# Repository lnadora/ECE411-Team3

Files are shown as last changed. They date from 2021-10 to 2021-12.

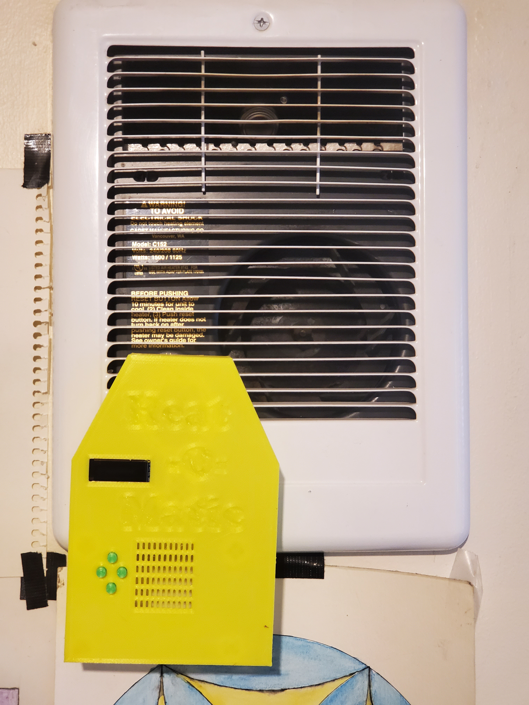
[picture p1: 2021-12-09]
20211205_145641.jpg

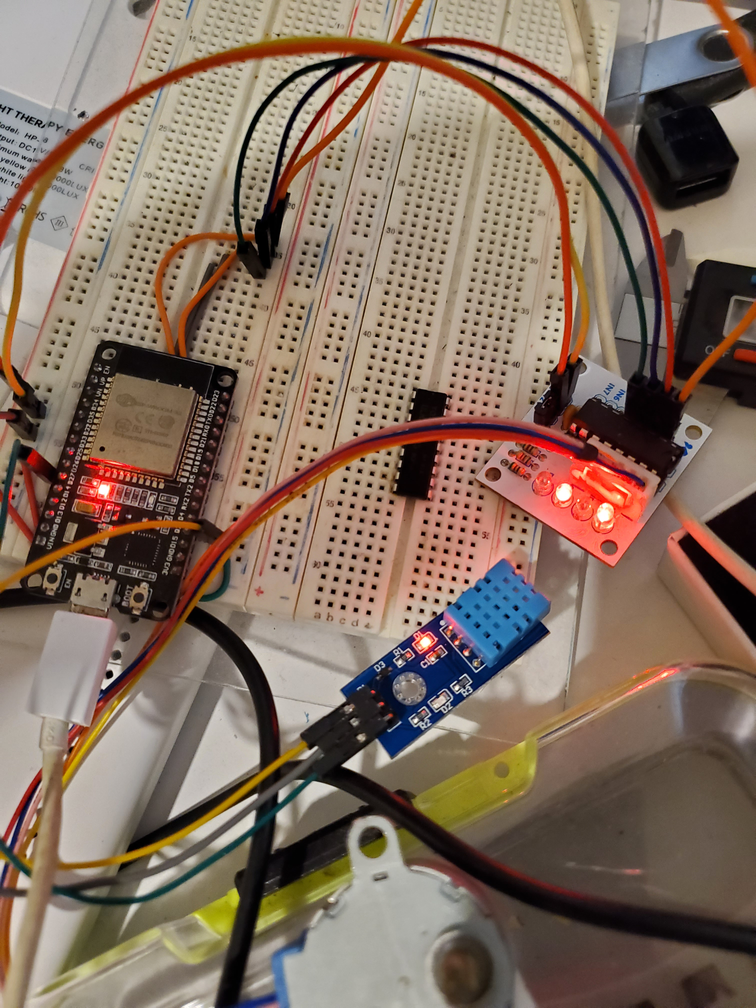
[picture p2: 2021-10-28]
Assignment Documentation/Week5 Assignment/breadboard.jpg

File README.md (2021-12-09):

# ECE411-Team3
Practicum Project for ECE 411

The project will attempt to connect ESP32 to the internet. After user use their device(phone,ipad,pc etc) connect with the wifi, Esp32 wifi module will send the Ip to the user.User can according to the IP go into the website and achieve the website interact.
To erase the credentials stored on the ESP32:     
    1.) uncomment the line:     
  ```//ESPAsync_wifiManager.resetSettings();   //reset saved settings:```     
    2.) upload and reset the ESP32, your credentials will be deleted.     
    3.) recomment the line     
    4.) reupload and reset the ESP32     

Once connected the device will present an IP address where the website is hosted on your local network.

Current program functionality:

    - Connects to the internet
    - Retrives temp from the sensor
    -- Samples every x seconds set by DHT_UPDATE_DELAY (currently every 1s)
    --- Should be changed to just using millis()
    - Prints temp,current and set temperature,and Ip  on the OLED
    -- Uses U9g2 library.
    --- lots of examples in the examples folder.  
    --- left some example code in the program commented out
    - Buttons move the stepper motor
    -- BUTTON_A turon on the system
    -- BUTTON_B tuen off the system
    -- BUTTON_C Increase the setting tem
    -- BUTTON_D decrease the setting tem
    -- Buttons labeled as BUTTON_A, BUTTON_B, BUTTON_C, BUTTON_D
    --- Button pins are 26,25,33,14 respectivly
    - Website can control stepper motor
    - Website can achieve the stable temperature system
    -- Through some exprimenting it was found how the data is transmitted
    --- This is documented in the .js file and the .cpp file.
    
Needs to be done

    -Menu
    -- Setup
    --- set time
    --- set leave time
    --- set arrive time
    - Change the timing function to millis()

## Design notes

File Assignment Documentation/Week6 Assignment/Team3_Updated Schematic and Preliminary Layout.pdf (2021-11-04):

Week 6 Schematic and Layout Team 3
11/4/2021
Notes:
- We still need to add a barrel jack and a AMS1117 3.3v voltage regulator to provide clean power to the board from a wall adapter. We got to this part late and would like to test it on the breadboard before we update the schematic as it works fine as it is now.
- The DHT11 will not be soldered to the board like it shows in the 3d view
- Annotating is still confusing… luke will make some edits to the screen printing

The Schematic for our design:

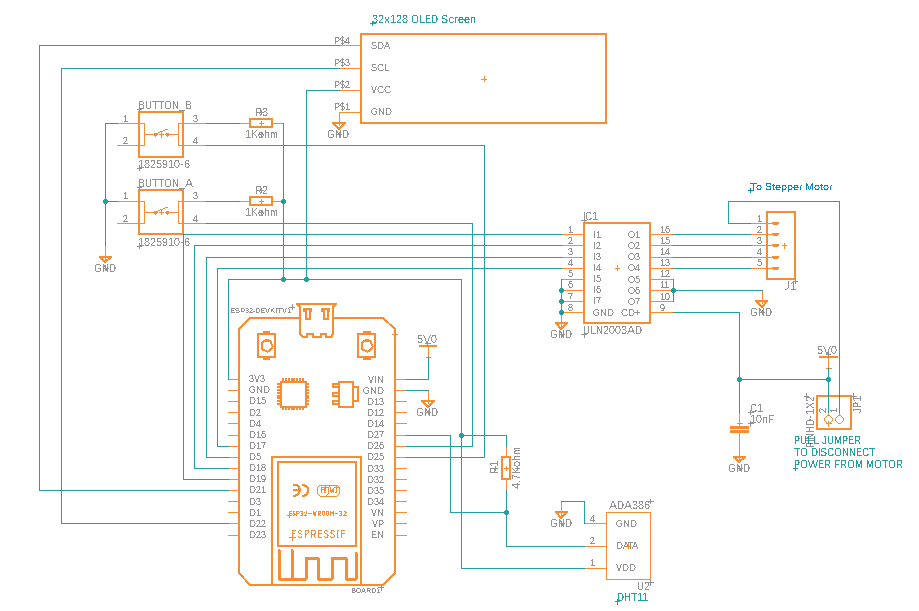
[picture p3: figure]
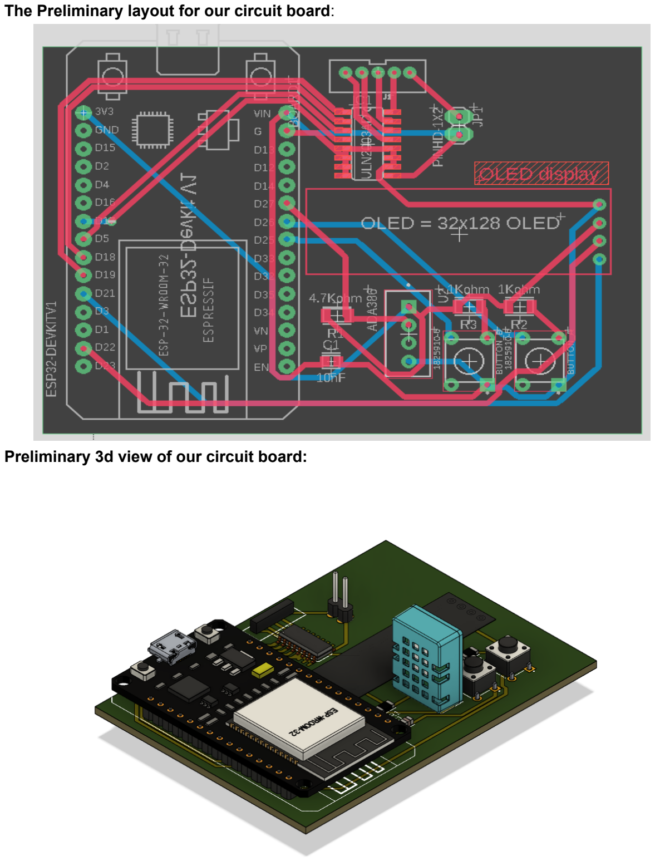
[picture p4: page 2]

The Preliminary layout for our circuit board:

Preliminary 3d view of our circuit board:

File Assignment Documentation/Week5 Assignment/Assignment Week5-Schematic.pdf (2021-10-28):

Practicum week 5: Schematic
Link to schematic: https://github.com/lnadora/ECE411-Team3/tree/main/CircuitBoard (schematic is made in Fusion 360 but exported as an Eagle filetype)

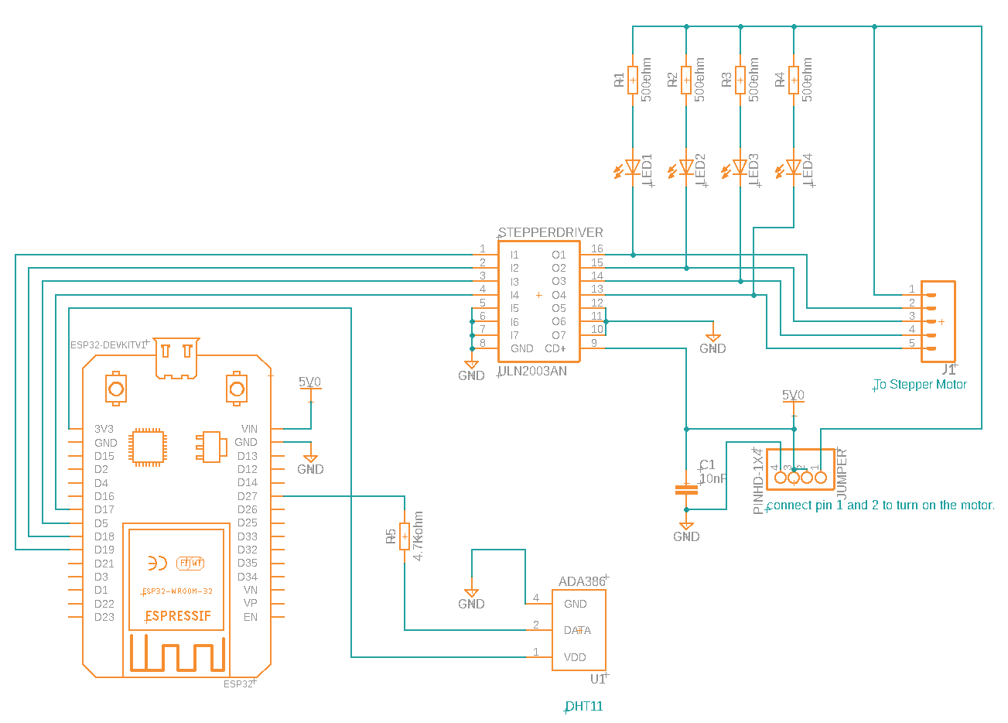
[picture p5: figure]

Todo:
1. Investigate separating the power of the motor from the power of the ESP32.
2. LED’s turn on when the motor is running… Pointless? Idk… They show the speed of the motor… but they flash really fast and it will be inside the case.
3. Use a power supply instead of USB to ESP to power the device
4. Change the DHT data line resistor R5 to a pull-up resistor connected to the 3.3v instead of inline to the data pin
5. Add buttons to manually turn the heater on or off
6. Look into BMS systems and see if it would be practical to implement a battery to our system

How it works
1. The ESP32 passes 5v through the USB port to the VIN pin.
a. We currently power the stepper motor with that 5V pin
2. Originally we powered the DHT11 with the +5V VIN pin. But since our ESP32 has 3.3v datalines the 5V was too much for them and produced many errors reading the temp.

3. The 4x1 pin jumper is a male header… But we really only need 2 pins to use a jumper that disables the stepper motor when removed.

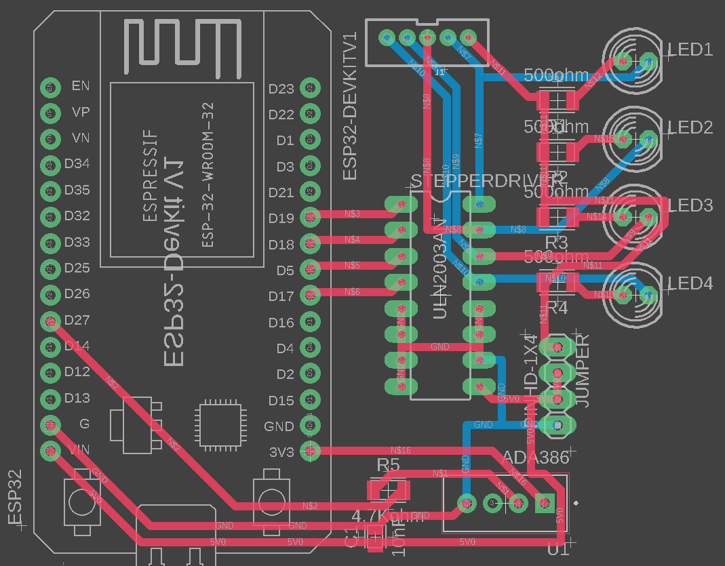
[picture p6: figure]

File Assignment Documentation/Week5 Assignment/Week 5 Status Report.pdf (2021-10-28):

Week 5 Status Report
Team 3
10/27/2021
Project Summary:
Our project is coming along nicely. So far we have our schematic for the PCB designed and all of our components are working with example code.

Completed Tasks for the week:
1. VS code and PlatformIO installed.
2. Build the circuit on the breadboard.
3. Use example code to make sure the parts we have work
4. Some basic testing based on the current code.
5. Using Fusion 360, we made the schematic of the circuit
6. Started a GANTT chart to keep everyone on track.

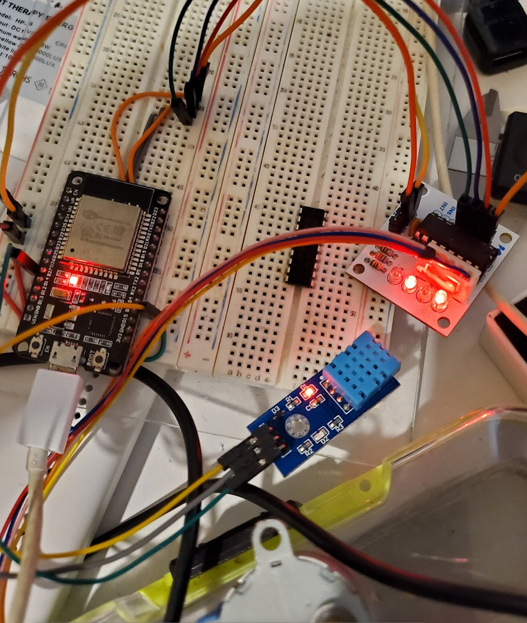
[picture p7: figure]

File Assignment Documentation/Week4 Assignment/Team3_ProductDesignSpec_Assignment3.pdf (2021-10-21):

## Product Design Specification

Team 3: Kai Han, Luke Hoskam, Luis Nadora, Zheng Zhang Professor Greenberg
ECE411
10/20/2021

### Executive Summary / Concept of Operations

Many apartment dwellers would like to have smart devices in their house but cannot because of the relative permeance of some devices. A heater in an apartment, for instance, may only present a user with a dial style thermostat knob to set an abstract temperature. This would leave no option to attach a smart thermostat. This would force an energy conscious renter to adjust the knob manually every time he left his apartment and when he returned.
Our device aims to fix that by attaching non-destructively to the thermostat knob and allow the user to program temperature settings though their local intranet.So people who are limited by the relative permeance of some devices but also would like to make the heater smarter will use it. The device will host a small webpage to allow the user to program either a constant temperature or set on-off times, for instance, automatically turn off when the user is at work. Basically, this device turns your standard knob controlled heater into a programmable thermostat without having to remove or damage parts of the building or equipment owned by the landlord.

### Brief Market Analysis

The intended customers are apartment dwellers who would like a smart heater but already had a dumb heater and renters who have a limited budget but want to maintain a constant temperature better the knob is capable. The device will non-destructively attach to the already installed heater knob and manipulate its inputs.
For now, our competitors are mainly manufacturers with complete replacement heating systems. If landlords replace the heater system with a smart heater, it will affect our sales of our project. The best aspect of our project is that we do not need to replace the original heater (which is not the property of the tenant), which can reduce waste. Replacing the heater will not only damage the walls or facilities in the original apartment, but also create a lot more waste. Thus, we will create a device that allows people to non-destructively convert an existing heater with a thermostat knob to a smart heater. The networked heater will also be controlled ‘smartly’ on the intranet. It not only saves electricity but also makes it easier and more fun to control the heater. Another type of competition is portable heaters, which are controlled/programmed by a smartphone app.
The price range for the permanently installed and portable smart devices is anywhere from $60-$250 and we are positive that we can build and sell our device within that price range.

### Requirements

Must requirements:
- Be lightweight
- Non-destructively attach to a heater knob
- Interface with the device through website
- Allow users to program on-off times through the website.
- Have a case
- Have a manufactured PCB
Should requirements:
- Powered by a battery
- Have an attractively designed case.
- Interface with buttons to control the motor.
May requirements:
- Realize the internet to control the temperature.
- Connect wirelessly to auxiliary thermostats to maintain an average set temperature.
- Have a display

### System Architecture

Level 1 Block Diagram for the Smart Heater

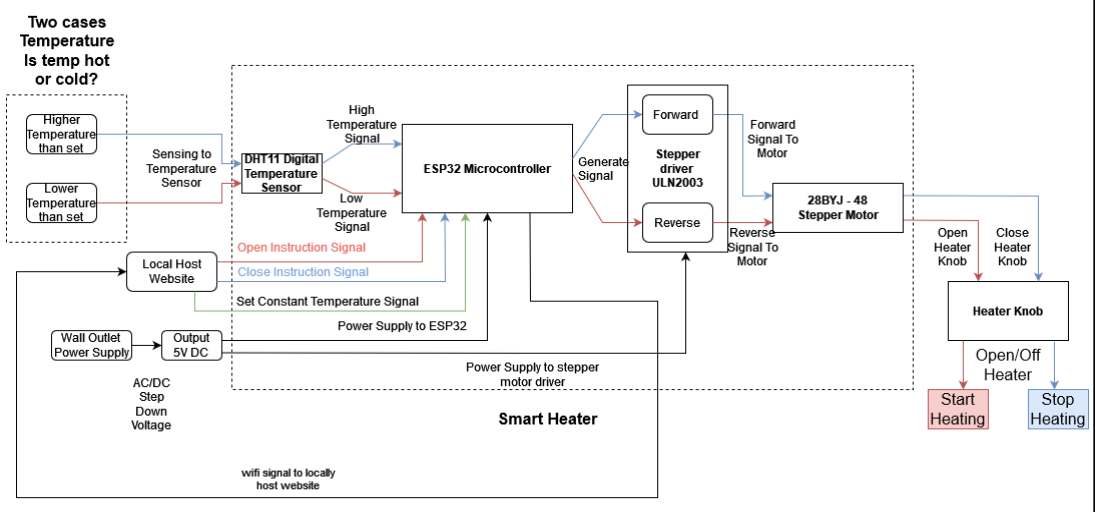
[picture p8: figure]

### Design Specification

- Processor: ESP Wroom 32 Devkit V1. 4
- The ESP Wroom 32 is a low-cost development board with a Dual-core CPU Xtensa LX6 clocked at 250MHz. It has: 25 digital I/O pins, 6 Analog inputs, and 2 digital-to-analog output pins, and 4MB of storage.
- Our project will use the ESP32 to process the signal from the DHT11 and, when appropriate, signal the stepper driver to manipulate the heater knob.

- Sensor: Temperature Sensor (DHT11) x 1.
- The DHT11 is a basic, ultra low-cost digital temperature and humidity sensor. It uses a capacitive humidity sensor and a thermistor to measure the surrounding air and outputs a digital signal on the data pin (no analog input pins needed).
- The project uses DHT11 sensors to detect the room temperature and then compare that temperature to the set temperature on the ESP32.
- Actuator: Stepper motor(28BYJ - 48) and Driver (ULN2003)x 1.
- Powered with 5v from the AC-DC wall adapter, the ULN2003 is a 16-pin IC. It has seven Darlington Pairs inside, where each can drive loads up to 50V and 500mA.
- 28BYJ-48 is a small, lightweight, unipolar, 5V stepper motor that inputs alternating pulse signals and rotates by converting these input signals into mechanical rotation by selectively turning on and off specific electromagnets.
- Our project will have 5v DC to the ULN2003 common pin. Then, when the ESP32 sends an HIGH signal to a particular pin on the ULN 2003 will output a clean 5v to the stepper motor. The stepper motor will connect to the heater knob through gears to turn the heater on and off.
- Power: E178074 AC-DC wall adapter.
- Input: 100-240AC,
- Output: 5v 1A wall adapter.
- Mechanical Design: Designed in Fusion 360 and printed using a 3D Printer.
- The software we will use to design the gears and the case will be Fusion 360. We will print the parts on one of three printers owned by group members.
- The case will include an opening for the DHT11 to extend outside the case. The circuit board, motor, gears and microcontroller will be inside the case.
- Development environment: Visual Studio Code, PlatformIO and GIT.
- We will use Visual Studio Code with the PlatformIO extension to program the ESP32.
- The group will stay connected and up to date with the project using GIT through github.com (https://github.com/lnadora/ECE411-Team3)

### Primitive CAD drawing

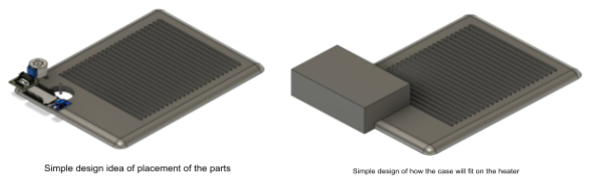
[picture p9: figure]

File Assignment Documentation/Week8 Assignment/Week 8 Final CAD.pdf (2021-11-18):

W

e

e

k

8

Fin

al C

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
tic:

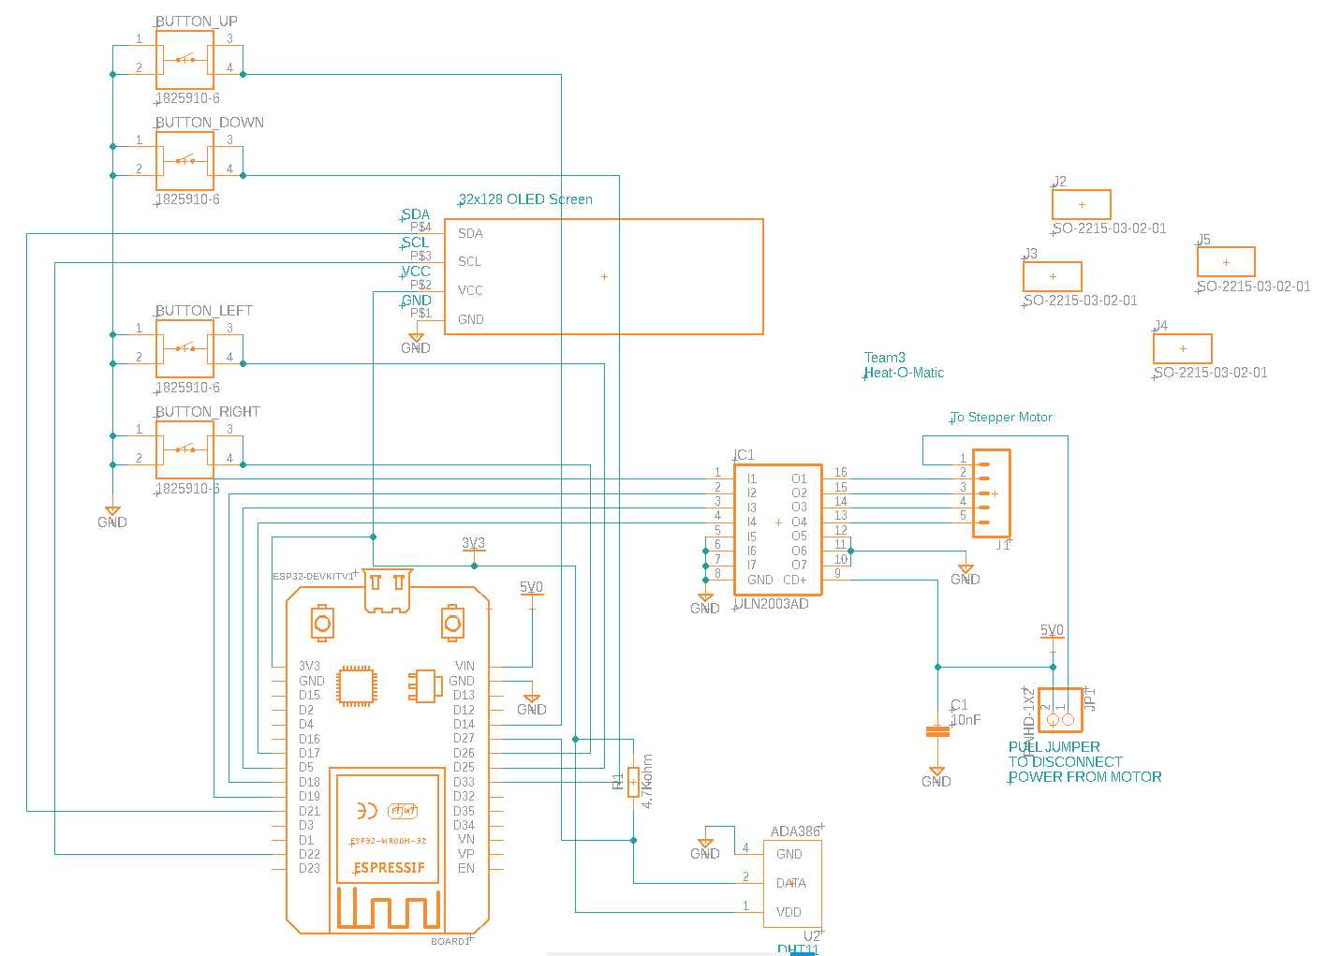
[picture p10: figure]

Board Layout:

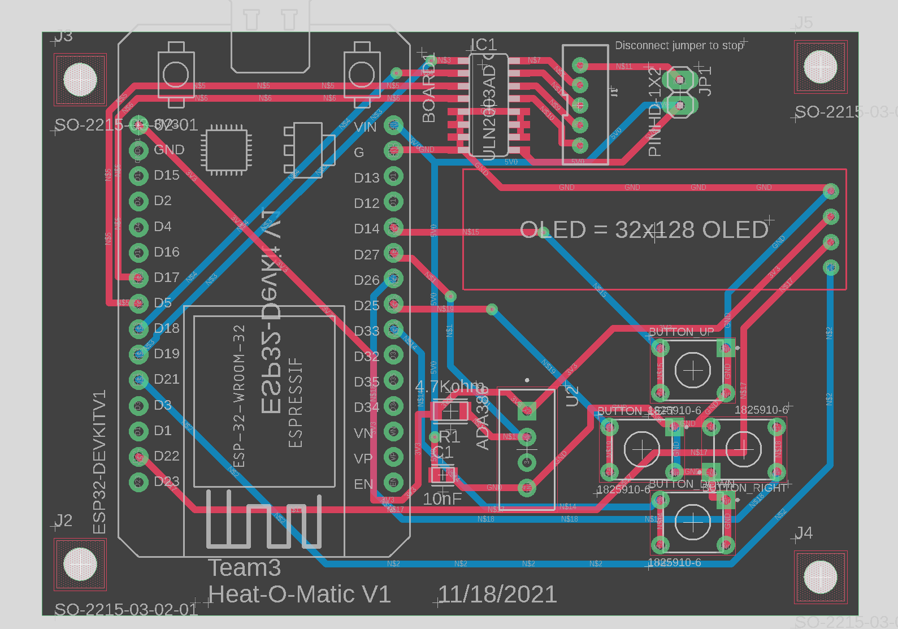
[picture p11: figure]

3d Model of board:

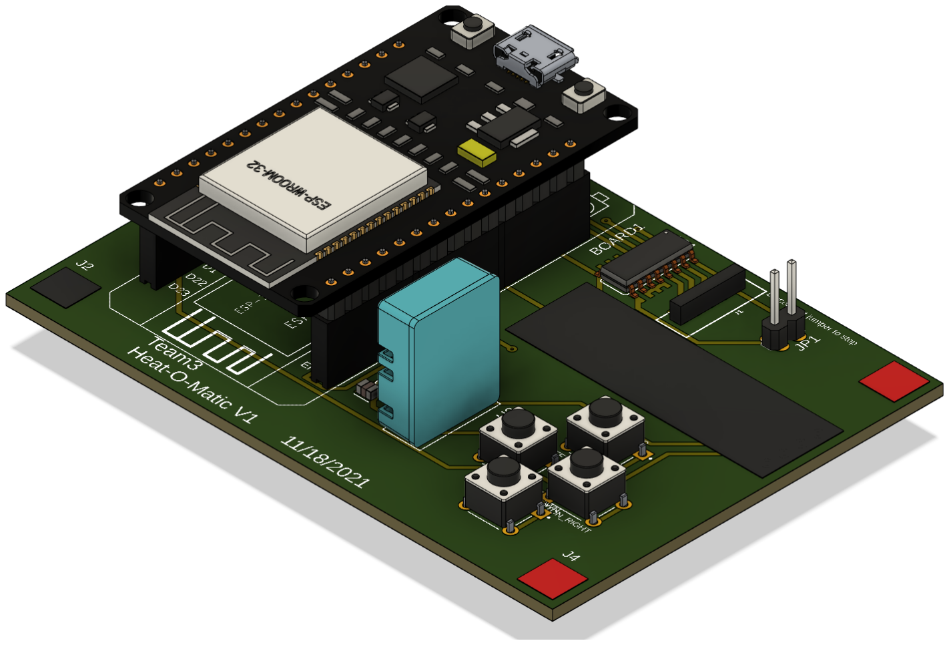
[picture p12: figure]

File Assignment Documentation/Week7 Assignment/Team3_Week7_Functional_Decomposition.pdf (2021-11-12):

# ECE 411 Team 3 Functional Decomposition for the Smart Heater System

Team Members: Kai Han, Luke Hoskam, Luis Nadora, Zheng Zhang

Level 0 Block Diagram

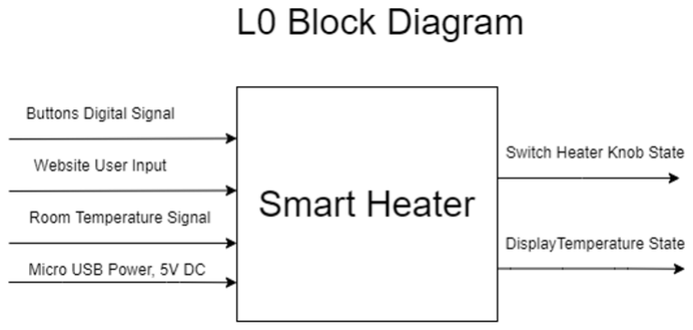
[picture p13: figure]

Module | Smart Heater
Inputs | Power: 5V dc. Buttons: Sends a digital signal to apply the settings desired by the user Room Temperature Signal: Sends a digital signal of ambient temperature and humidity Website User Input: Local website send user input data and getting feedback from microcontroller to declare when to turn the knob
Outputs | DisplayTemperature State: Smart heater sends data using the I2C protocol to the OLED screen to display temperature state Switch Heater Knob State: The stepper motor receives a digital signal turning the knob position.
Functionality | The Smart Heater turns the knob on a heater unit a certain amount of steps to turn the heater on or off. The start and end time for the system is determined by the user through the WebSocket website, as well as the desired room temp at that time. Buttons are used to set the start and end times of the system without going through the website. The ambient temperature and humidity of the room is also displayed on the OLED display screen for the user to read.

Level 1 Block Diagram

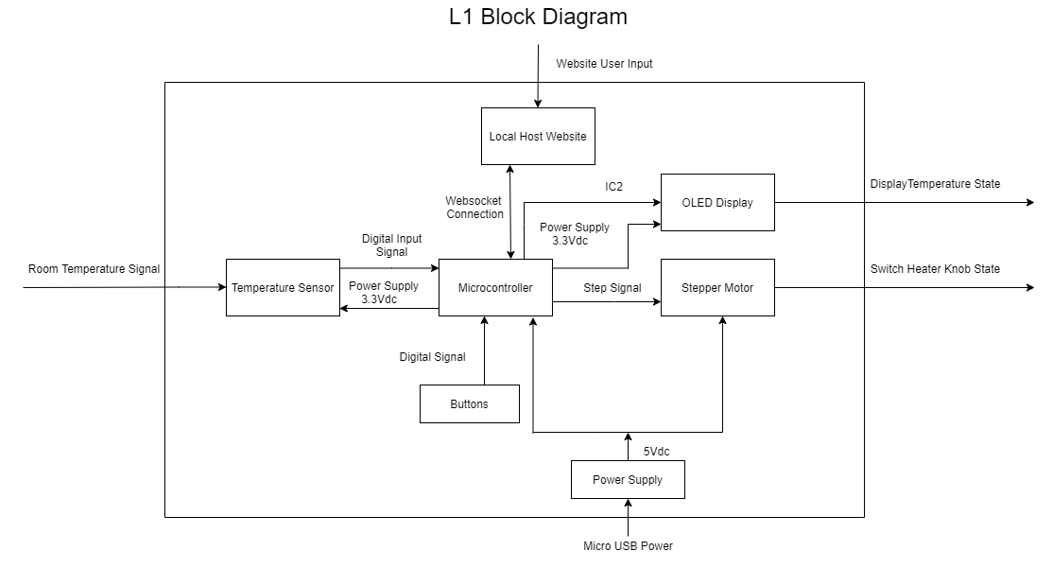
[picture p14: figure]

Temperature Sensor: Level 1

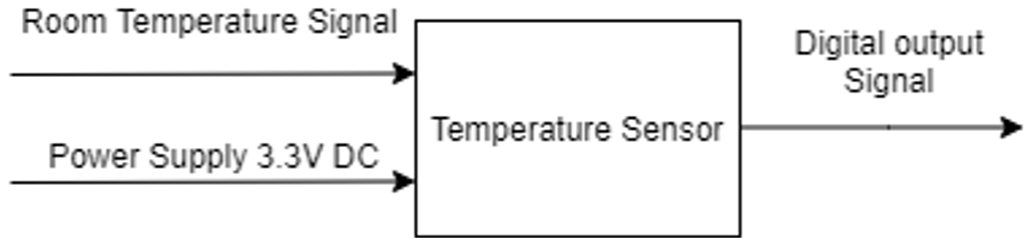
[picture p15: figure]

Module | Temperature Sensor
Inputs | Power: 3.3V dc from microcontroller Room Temperature Signal：Sends a digital signal of ambient temperature and humidity
Outputs | Digital output signal: Get the current temperature and humidity data from the sensor, and send a digital signal to the microcontroller.
Functionality | Sensing the surrounding temperature and sending a digital signal to the microcontroller

Microcontroller: Level 1

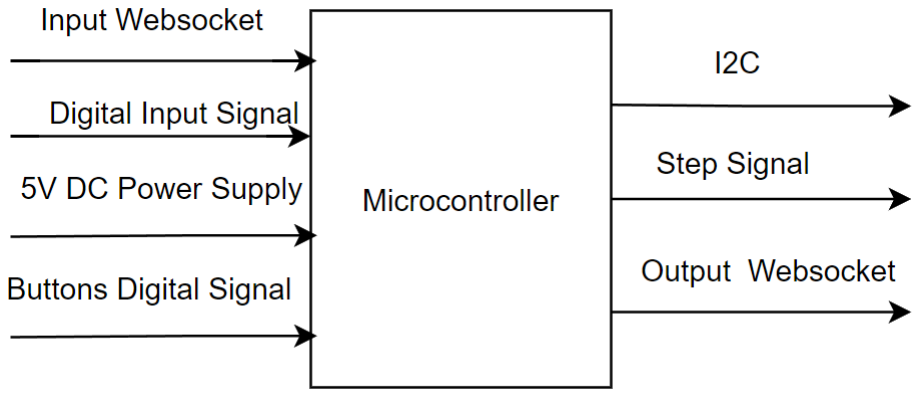
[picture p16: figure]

Module | Microcontroller
Inputs | Input Websocket ：Local website sends user input data to declare when to turn the knob Digital input signal：Ambient temperature data from the temperature sensor, to be used to compare the ambient temperature with the set temperature to determine whether it is consistent Power supply：5V DC Buttons：Manually control smart heater switch, timer
Outputs | I2C：Sends data for the OLED screen to display temperature state Step signal: Signal sent to the stepper motor to change the knob position Output websocket：Microcontroller establishes WebSocket Connection to setup the local website
Functionality | The microprocessor can complete operations such as fetching instructions, executing instructions, and exchanging information with external memory and logic components

Local Host Website: Level 1

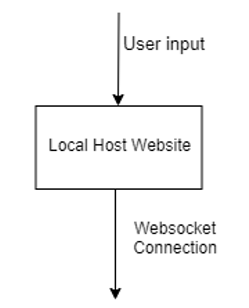
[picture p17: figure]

Module | Local host website
Inputs | User Input： The user gives instructions to the webpage by visiting the webpage, choosing the temperature and starting time the user would like.
Outputs | Websocket connection: Local website sends user input data through the Websocket connection to the microcontroller, thus communicating the desired start and end times for the heater to be turned on.
Functionality | Our project hopes to showcase the “smartification” of the heater through web design. The user gives instructions to the webpage to get the function they desire.

Stepper Motor: Level 1

Module | Stepper motor
Inputs | Power: 5Vdc Step signal: Send a continuous and stable signal to the motor to make the motor rotate
Outputs | Switch heater knob state:The stepper motor receives the step signal, turning the knob position.
Functionality | The motor has a gear system attached to it so that it has enough torque to rotate the heater system control knob.

OLED Display: Level 1

Module | OLED display
Inputs | Power: 3.3V DC Voltage I2C: The data from the microcontroller telling the OLED screen what to display
Outputs | Display temperature state: OLED Screen displays the current temperature and humidity information of the room.
Functionality | The OLED Screen displays the current temperature and humidity of the room according to the I2C protocol sent by the microcontroller.

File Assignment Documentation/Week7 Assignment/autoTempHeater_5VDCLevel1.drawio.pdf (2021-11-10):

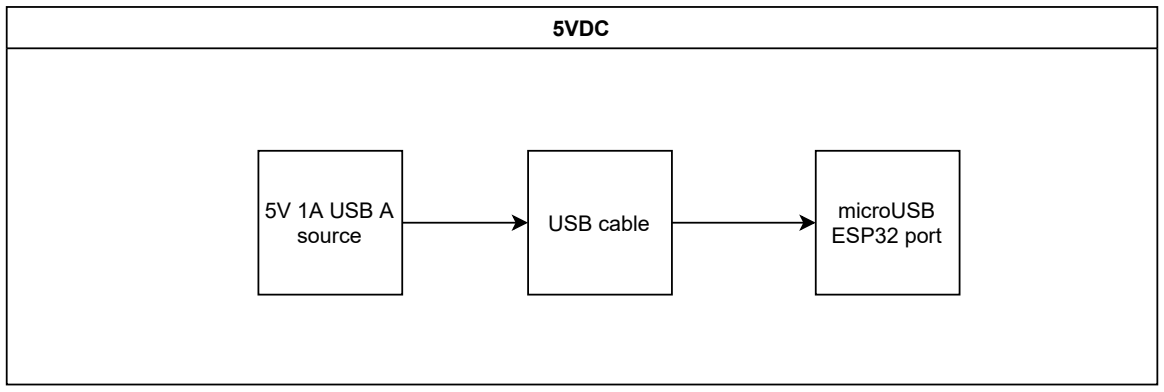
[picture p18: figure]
5VDC; 5V 1A USB A source; USB cable; microUSB; ESP32 port

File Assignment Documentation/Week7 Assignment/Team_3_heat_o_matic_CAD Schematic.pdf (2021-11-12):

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
tic:

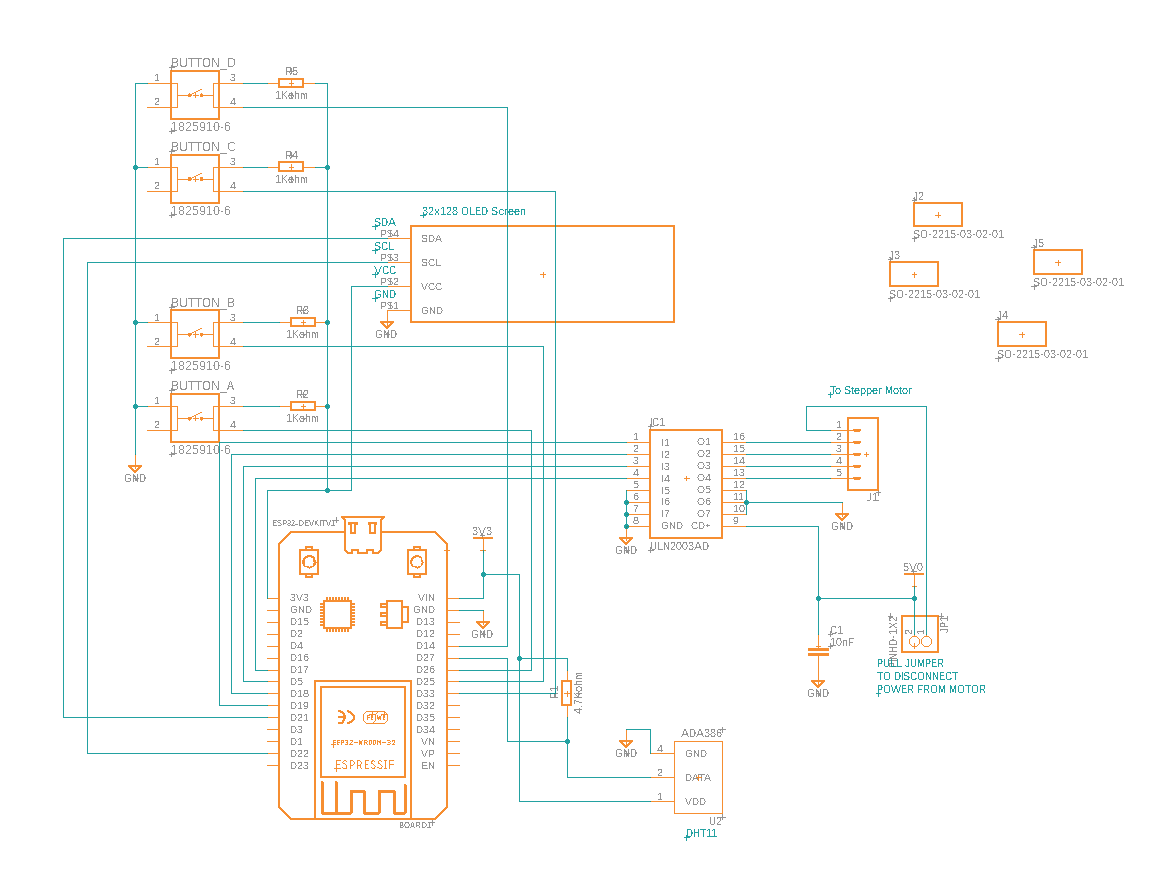
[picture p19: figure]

Layout:

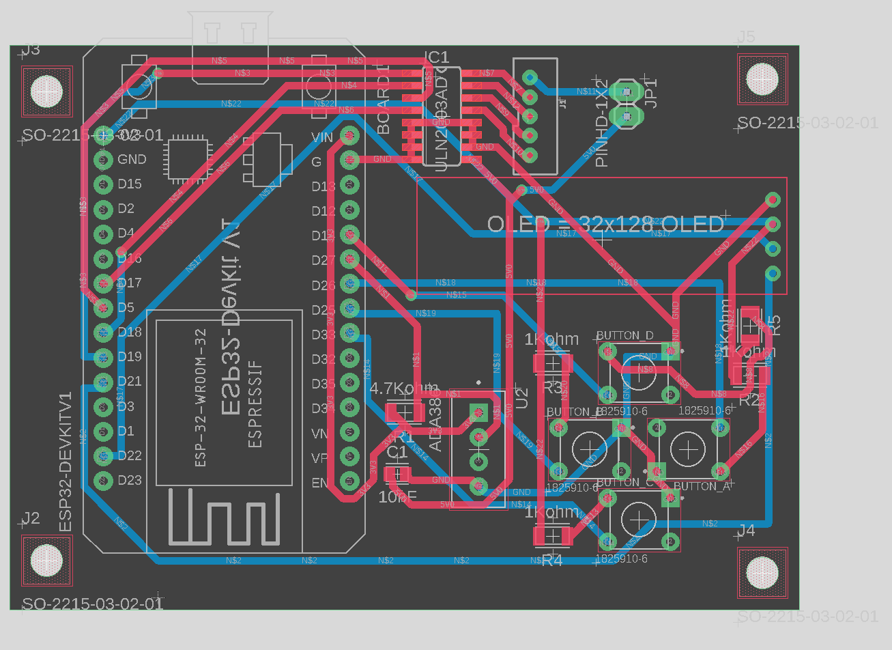
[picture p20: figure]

3d Model:

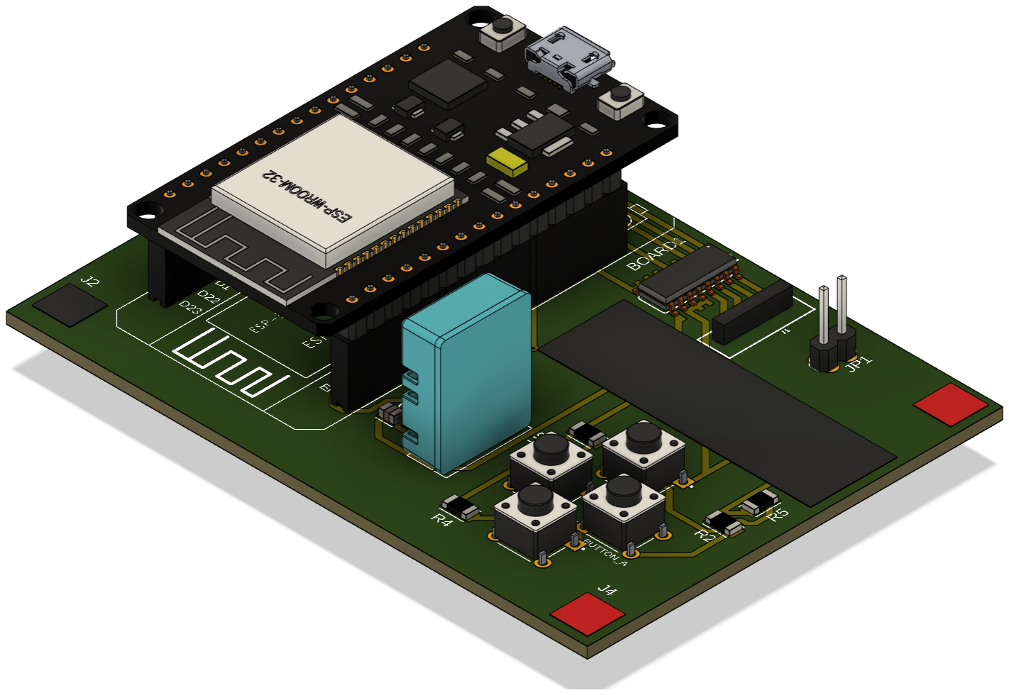
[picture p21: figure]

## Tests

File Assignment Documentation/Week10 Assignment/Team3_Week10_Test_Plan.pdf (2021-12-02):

## Week 10 Test Plan Team 3 “Heat-o-Matic”

12/03/2021

## Team Members: Zheng Zhang, Luis Nadora, Luke Hoskam, Kai Han

Test Author:Zheng Zhang

Test Case Name: | System test | Test ID #:
Description: | Test system by using different methods to change the temperature of the environment, so as to observe after the smart heater has passed the webpage default temperature of 24°C. The heater can be switched on and off by changing the indoor temperature | Type: | □ white box ☑ black box □ _____________

Tester Information
| Name of Tester: | Zhengzhang, Kai Han | Date: | 11/27/2021
| HW/SW Version: | 1.0 | Time: | 2:00 pm
| Setup: | Use a hair dryer to raise the temperature for the DHT11 temperature sensor, and place it outdoors to reduce the temperature to simulate the indoor temperature
TEST | Action | Expected Output： stepper motor state | PASS | FAIL | N/A | Comments
1 | Open the window and place the board outside the window to lower the sensor temperature to 20 °C | The stepper motor rotates 180° and the heater turns on | | | | Setting temperature less than the indoor temperature，system start to work，stepper motor rotates 180° and the heater turns on
2 | Use a hair dryer to raise the temperature sensed to 26°C | The stepper motor rotates 180° and the heater turns off | | | | Setting the temperature over the indoor temperature，system does not work，the steeper turns back to the original position.
3 | Use a hair dryer to raise the temperature sensed to 28°C | The stepper motor not move and the heater turns off | | | | Increasing the temperature after the system has already turned on the heater，the system keep to stay off.
4 | Open the window and place the board outside the window to lower the sensor temperature to 20 ° | The stepper motor rotates 180° and the heater turns on | | | | Setting the temperature smaller than the indoor temperature，the system turns on again, stepper motor rotates 180° and the heater turns on
| Overall test result: | | | | | The project can perfectly work with the temperature change.

Detailed Description：Our project depends on the user setting the temperature to tell the system to turn the heater on or off. Users will set the specific temperature on the website, the DHT11 sensor will detect the temperature and send a digital signal to the esp32 microcontroller to move the heater knob in the appropriate position via the stepper motor. Therefore, proper communication between the input temperature and output stepper motor control is very important. We will test the system by simulating indoor temperature and using different methods to change the temperature of the environment, so as to observe the result after the smart heater has passed the webpage default temperature of 24°C. The heater should be switched on or off depending on the indoor temperature.

Test Author: Zheng Zhang

Test Case Name: | Component tests | Test ID #:
Description: | Test to confirm the basic function of the heat-o-matic project. | Type: | ☑white box □ black box □ ________

Tester Information
| Name of Tester: | Zheng Zhang, Kai Han | Date: | 11/30/2021
| HW/SW Version: | 1.0 | Time: | 4:00pm
| Setup: | Build the circuit on the breadboard and test the basic function of each component.
STEP | Test part: | Expected Result | PASS | FAIL | N/A | Comments
1 | DHT11 temperature sensor | DHT 11 can detect the surrounding temperature | | | | The temperature sensor sometimes displays packet loss behavior, and occasionally displays nan°, but because the temperature sensor refreshes in real time and the frequency is twice per second, it does not affect the use of the function
2 | Stepper motor | Stepper motor can accept the digital signal to Rotate 180° | | | | The motor can successfully receive the signal to complete the work
3 | Website display | Website can accept the ESP 32 offer IP , also can create it on the local host and normally display current temperature, user setting temperature, and system status | | | | When multiple people connect to the same wifi hotspot, it may cause the website to display normally， should fix this bug.
4 | OLED display | OLED can display the current temperature，user setting temperature and website IP | | | | The OLED connection is correct and properly displays the information for the user
5 | Websocket Connection | Users can use the website to set the expected temperature to make the heater turn on or off. | | | | Websocket connection works properly between esp32 and the website.
| Overall test result: | | | | | The basic functions can be implemented very well. Although the DHT11 occasionally loses packets, it does not affect the use. The occasional behavior that cannot be displayed on the multi-person connection web page needs to be repaired.

Detialed Description：To make sure the project works well, we need to do the white box test to make sure every part of the project works well. So we will build each different part on a breadboard, to test if the function of every component works properly. We must test if the DHT11 temperature sensor can detect the surrounding temperature correctly, if the stepper motor can accept the digital signal to Rotate 180° to turn on or off the system, if the website can be created properly on the local host. We must also test if the OLED can display the current temperature, the desired temperature, and the website IP for the Websocket Connection so that the user can set the desired temperature from the website.
If each part individually functions properly then it illustrates that the function of the system as a whole functions properly as well.

Test Author:Luis Nadora

Test Case Name: | Button Test | Test ID #:
Description: | Press each button to ensure that it is being detected properly by the ESP32 Microcontroller. | Type: | □ white box ☑ black box □ _____________

Tester Information
| Name of Tester: | | Date:
| HW/SW Version: | 1.0 | Time:
| Setup: | Observe the confirmation of each button press by looking at the output script via microcontroller program on the monitor.
TEST | Action | Expected Output： | PASS | FAIL | N/A | Comments
1 | Press Button A | Output Script on the monitor saying “Button A Was Pressed”
2 | Press Button B | Output Script on the monitor saying “Button B Was Pressed”
3 | Press Button C | Output Script on the monitor saying “Button C Was Pressed”
4 | Press Button D | Output Script on the monitor saying “Button D Was Pressed”
| Overall test result:

Detailed Description: The purpose of this test is to simply ensure that each of the buttons are correctly connected to the system and communicate properly with the rest of the system through the microcontroller. A simple program will be needed in order to conduct this test. If the result of any of the button tests results in a failure, there may be something incorrect with the assembly of the system. Check to ensure that the buttons are correctly connected to the appropriate pins of the microcontroller, and check the program to make sure that there are no errors resulting from the test code.

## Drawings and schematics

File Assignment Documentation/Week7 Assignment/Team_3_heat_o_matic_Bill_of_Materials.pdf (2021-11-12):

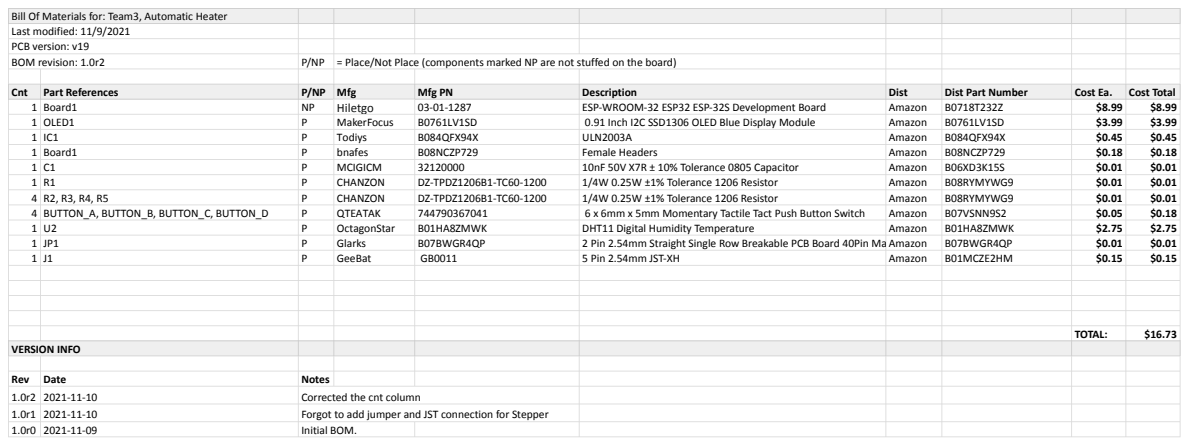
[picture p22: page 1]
BOM revision: 1.0r2; P/NP = Place/Not Place (components marked NP are not stuffed on the board); Cnt; Part References; P/NP Mfg; Mfg PN; Description; Dist; Dist Part Number; Cost Ea.; Cost Total; 1 Board1; Hiletgo; ESP-WROOM-32 ESP32 ESP-32S Development Board; Amazon; 1 OLED1; MakerFocus; 0.91 Inch I2C SSD1306 OLED Blue Display Module; Todiys; B084QFX94X; ULN2003A; bnafes; B08NCZP729; Female Headers; MCIGICM; 10nF 50V X7R ± 10% Tolerance 0805 Capacitor; CHANZON; DZ-TPDZ1206B1-TC60-1200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

Bill Of Materials for: Team3, Automatic Heater
Last modified: 11/9/2021
PCB version: v19

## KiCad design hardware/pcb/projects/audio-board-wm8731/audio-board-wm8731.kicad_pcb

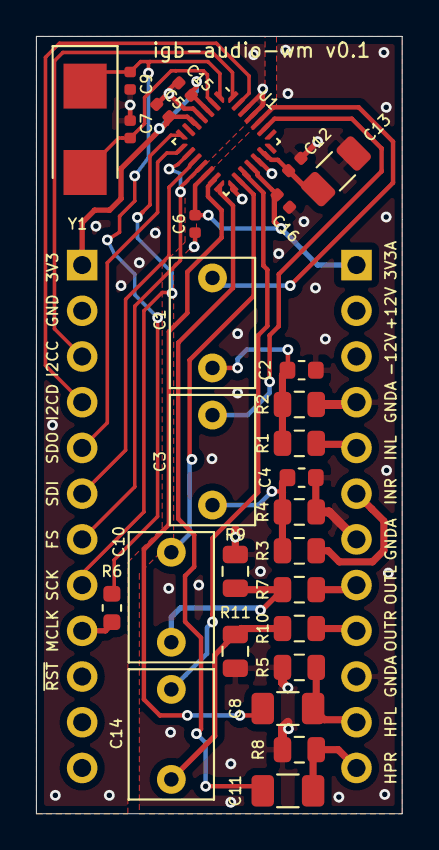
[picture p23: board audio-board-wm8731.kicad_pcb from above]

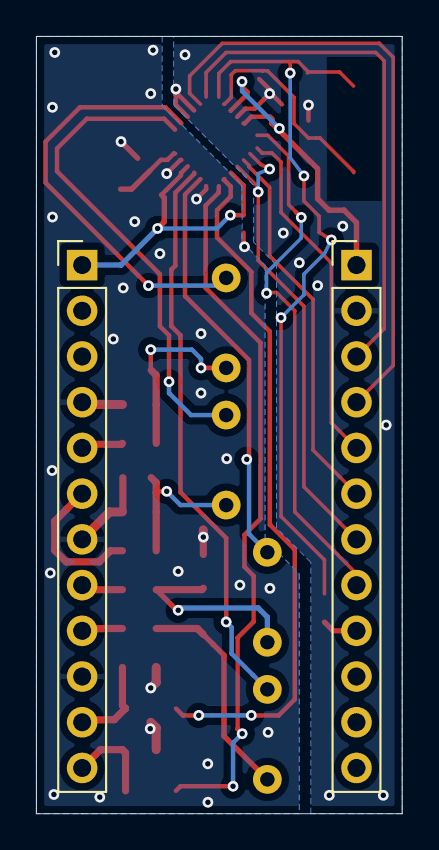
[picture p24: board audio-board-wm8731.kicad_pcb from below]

Board: 2 copper layers, 20.3 x 43.2 mm, 31 parts (2 on the bottom side), 30 nets.

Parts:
C1, C3, C10, C14: 1u; C_Rect_L7.0mm_W4.5mm_P5.00mm
C2, C4: 220p; C_0603_1608Metric
C5, C6, C12, C15, C16: 100n; C_0402_1005Metric
C7, C9: 18p; C_0402_1005Metric
C8, C11: 100u; C_1206_3216Metric
C13: 10u; C_1206_3216Metric
J1, J2: Conn_01x12; PinHeader_1x12_P2.54mm_Vertical
R1, R2, R3, R4: 10k; R_0805_2012Metric
R5, R8, R9, R11: 100k; R_0805_2012Metric
R6: 0; R_0603_1608Metric
R7, R10: 100; R_0805_2012Metric
U1: wm8731_qfn; QFN-28_4x4mm_P0.5mm
Y1: 12.288MHz; Crystal_SMD_Abracon_ABM3-2pin_5.0x3.2mm_hand

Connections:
+3.3VA: C6.2, C16.2, J1.1, U1.12, U1.18
+3V3: C5.2, C15.2, J2.1, U1.3, U1.5
/ADC_L: C1.2, U1.24
/ADC_R: C3.2, U1.23
/DAC_L: C10.2, U1.16
/DAC_R: C14.2, U1.17
/HP_OUT_L: C8.2, J1.11, R5.2
/HP_OUT_R: C11.2, J1.12, R8.2
/I2C_SCL: J2.3, U1.28
/I2C_SDA: J2.4, U1.27
/I2S_FS: J2.7, U1.9, U1.11
/I2S_MCLK: J2.9, R6.1
/I2S_SCK: J2.8, U1.7
/I2S_SDI: J2.6, U1.10
/I2S_SDO: J2.5, U1.8
/LINE_IN_L: J1.5, R1.2
/LINE_IN_R: J1.6, R3.2
/LINE_OUT_L: J1.8, R7.2
/LINE_OUT_R: J1.9, R10.2
GND: C5.1, C7.2, C9.2, C15.1, J2.2, U1.4, U1.25, U1.26
GNDA: C2.1, C4.1, C6.1, C12.2, C13.2, C16.1, J1.4, J1.7, J1.10, R2.2, R4.2, R5.1, R8.1, R9.1, R11.1, U1.15, U1.19
unnamed: C1.1, C2.2, R1.1, R2.1
unnamed: C3.1, C4.2, R3.1, R4.1
unnamed: C7.1, U1.2, Y1.2
unnamed: C8.1, U1.13
unnamed: C9.1, R6.2, U1.1, Y1.1
unnamed: C10.1, R7.1, R9.2
unnamed: C11.1, U1.14
unnamed: C12.1, C13.1, U1.20
unnamed: C14.1, R10.1, R11.2

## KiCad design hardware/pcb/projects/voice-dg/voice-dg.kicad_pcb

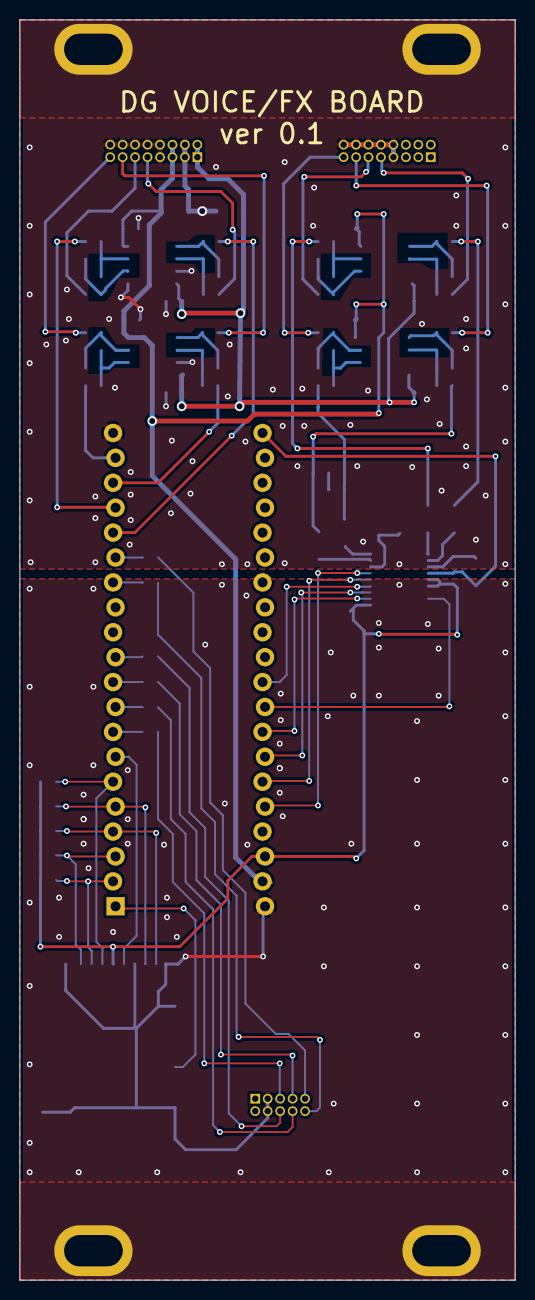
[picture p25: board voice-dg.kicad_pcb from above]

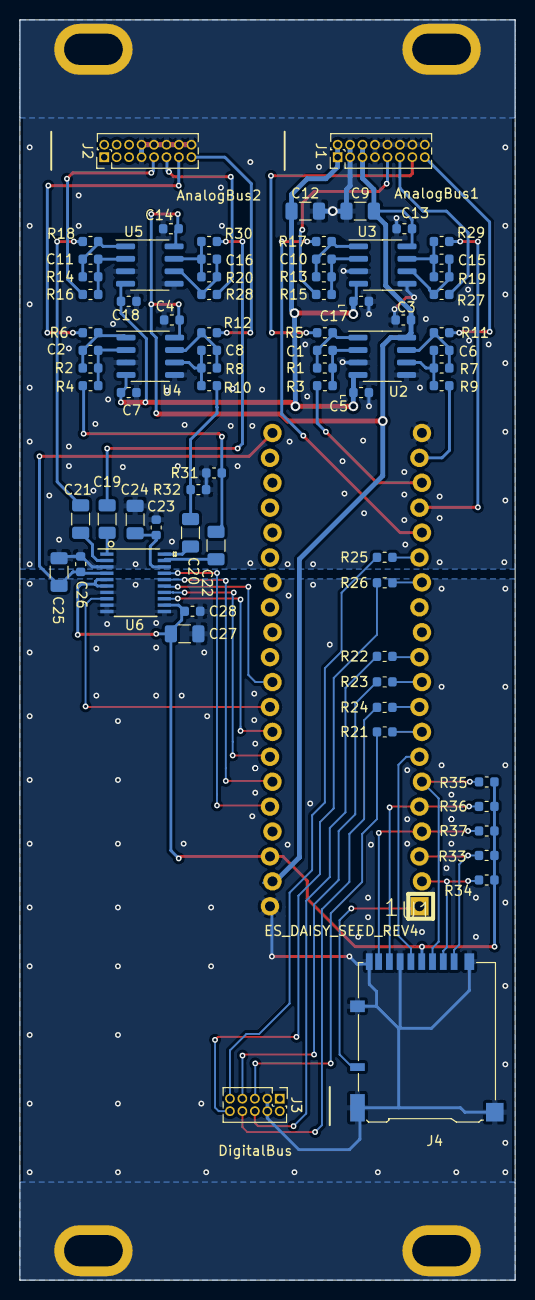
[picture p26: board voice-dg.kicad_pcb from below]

Board: 2 copper layers, 50.5 x 128.5 mm, 75 parts (75 on the bottom side), 68 nets.

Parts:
C1, C2, C6, C8, C10, C11, C15, C16: 12p; C_0603_1608Metric
C3, C4, C5, C7, C13, C14, C17, C18, C23, C26, C28: 100n; C_0603_1608Metric
C9, C12: 22u; C_1206_3216Metric
C19, C20, C21, C22, C25, C27: 10u; C_1206_3216Metric
C24: 2.2u; C_1206_3216Metric
J1: AnalogBus; PinHeader_2x08_P1.27mm_Vertical
J2: AnalogBusEx; PinHeader_2x08_P1.27mm_Vertical
J3: DigitalBus; PinHeader_2x05_P1.27mm_Vertical
J4: Micro_SD_Card_Det_Hirose_DM3AT; microSD_HC_Hirose_DM3AT-SF-PEJM5_hand
R1, R2, R7, R8, R15, R16, R27, R28: 100k; R_0603_1608Metric
R3, R4, R9, R10, R13, R14, R19, R20: 10k; R_0603_1608Metric
R5, R6, R11, R12, R17, R18, R29, R30: 470; R_0603_1608Metric
R21, R22, R23, R24, R25, R26: 47; R_0603_1608Metric
R31, R32, R33, R34, R35, R36, R37: 47k; R_0603_1608Metric
U1: ES_DAISY_SEED_REV4; ES_DAISY_SEED
U2, U3, U4, U5: OPA2134; SOIC-8_3.9x4.9mm_P1.27mm
U6: AK4556VT

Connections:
+3.3VA: C25.2, C26.1, U1.21, U6.4
+3V3: C27.2, C28.1, J4.4, R33.2, R34.2, R35.2, R36.2, R37.2, U1.38, U6.5, U6.6, U6.12
+12V: C3.1, C4.1, C9.2, C13.1, C14.1, J1.5, J1.6, U1.39, U2.8, U3.8, U4.8, U5.8
-12V: C5.1, C7.1, C12.1, C17.1, C18.1, J1.1, J1.2, U2.4, U3.4, U4.4, U5.4
/AK4556_RST: U1.36, U6.17
/AnalogIn1: J1.9, R15.2
/AnalogIn2: J1.11, R27.2
/AnalogIn3: J2.9, R16.2
/AnalogIn4: J2.11, R28.2
/AnalogOut1: J1.13, R5.1
/AnalogOut2: J1.15, R11.1
/AnalogOut3: J2.13, R6.1
/AnalogOut4: J2.15, R12.1
/DG_AUDIO_IN_L: R17.1, U1.16
/DG_AUDIO_IN_R: R29.1, U1.17
/DG_AUDIO_OUT_L: R3.2, U1.18
/DG_AUDIO_OUT_R: R9.2, U1.19
/EX_AUDIO_IN_L: C21.1, R18.1
/EX_AUDIO_IN_R: C19.1, R30.1
/EX_AUDIO_OUT_L: C22.2, R4.2, R31.2
/EX_AUDIO_OUT_R: C20.2, R10.2, R32.2
/SAI2_FS_B: U1.34, U6.14
/SAI2_MCLK_B: U1.31, U6.15
/SAI2_SCK_B: U1.35, U6.16
/SAI2_SD_A: U1.33, U6.13
/SAI2_SD_B: U1.32, U6.8
/SD_CLK: J4.5, U1.7
/SD_CMD: J4.3, R35.1, U1.6
/SD_D0: J4.7, R36.1, U1.5
/SD_D1: J4.8, R37.1, U1.4
/SD_D2: J4.1, R33.1, U1.3
/SD_D3: J4.2, R34.1, U1.2
/SPI_MISO: R23.2, U1.10
/SPI_MOSI: R22.1, U1.11
/SPI_SCK: R24.1, U1.9
/USART_RX: R25.2, U1.15
/USART_TX: R26.1, U1.14
/~SD_SW: J4.10, U1.1
/~SPI_CS: R21.2, U1.8
GND: C27.1, C28.2, J3.3, J3.4, J4.6, J4.9, J4.11, U1.40, U6.7, U6.9, U6.10, U6.11
GNDA: C3.2, C4.2, C5.2, C7.2, C9.1, C12.2, C13.2, C14.2, C17.2, C18.2, C23.2, C24.1, C25.1, C26.2, J1.3, J1.4, J1.7, J1.8, J1.10, J1.12, J1.14, J1.16, J2.7, J2.8, J2.10, J2.12, J2.14, J2.16, R31.1, R32.1, U1.20, U2.3, U2.5, U3.3, U3.5, U4.3, U4.5, U5.3, U5.5, U6.3
unnamed: C1.1, R1.1, R5.2, U2.1
unnamed: C1.2, R1.2, R3.1, U2.2
unnamed: C2.1, R2.1, R6.2, U4.1
unnamed: C2.2, R2.2, R4.1, U4.2
unnamed: C6.1, R7.1, R11.2, U2.7
unnamed: C6.2, R7.2, R9.1, U2.6
unnamed: C8.1, R8.1, R12.2, U4.7
unnamed: C8.2, R8.2, R10.1, U4.6
unnamed: C10.1, R13.1, R17.2, U3.1
unnamed: C10.2, R13.2, R15.1, U3.2
unnamed: C11.1, R14.1, R18.2, U5.1
unnamed: C11.2, R14.2, R16.1, U5.2
unnamed: C15.1, R19.1, R29.2, U3.7
unnamed: C15.2, R19.2, R27.1, U3.6
unnamed: C16.1, R20.1, R30.2, U5.7
unnamed: C16.2, R20.2, R28.1, U5.6
unnamed: C19.2, U6.1
unnamed: C20.1, U6.20
unnamed: C21.2, U6.2
unnamed: C22.1, U6.19
unnamed: C23.1, C24.2, U6.18
unnamed: J3.5, R21.1
unnamed: J3.6, R22.2
unnamed: J3.7, R23.1
unnamed: J3.8, R24.2
unnamed: J3.9, R25.1
unnamed: J3.10, R26.2

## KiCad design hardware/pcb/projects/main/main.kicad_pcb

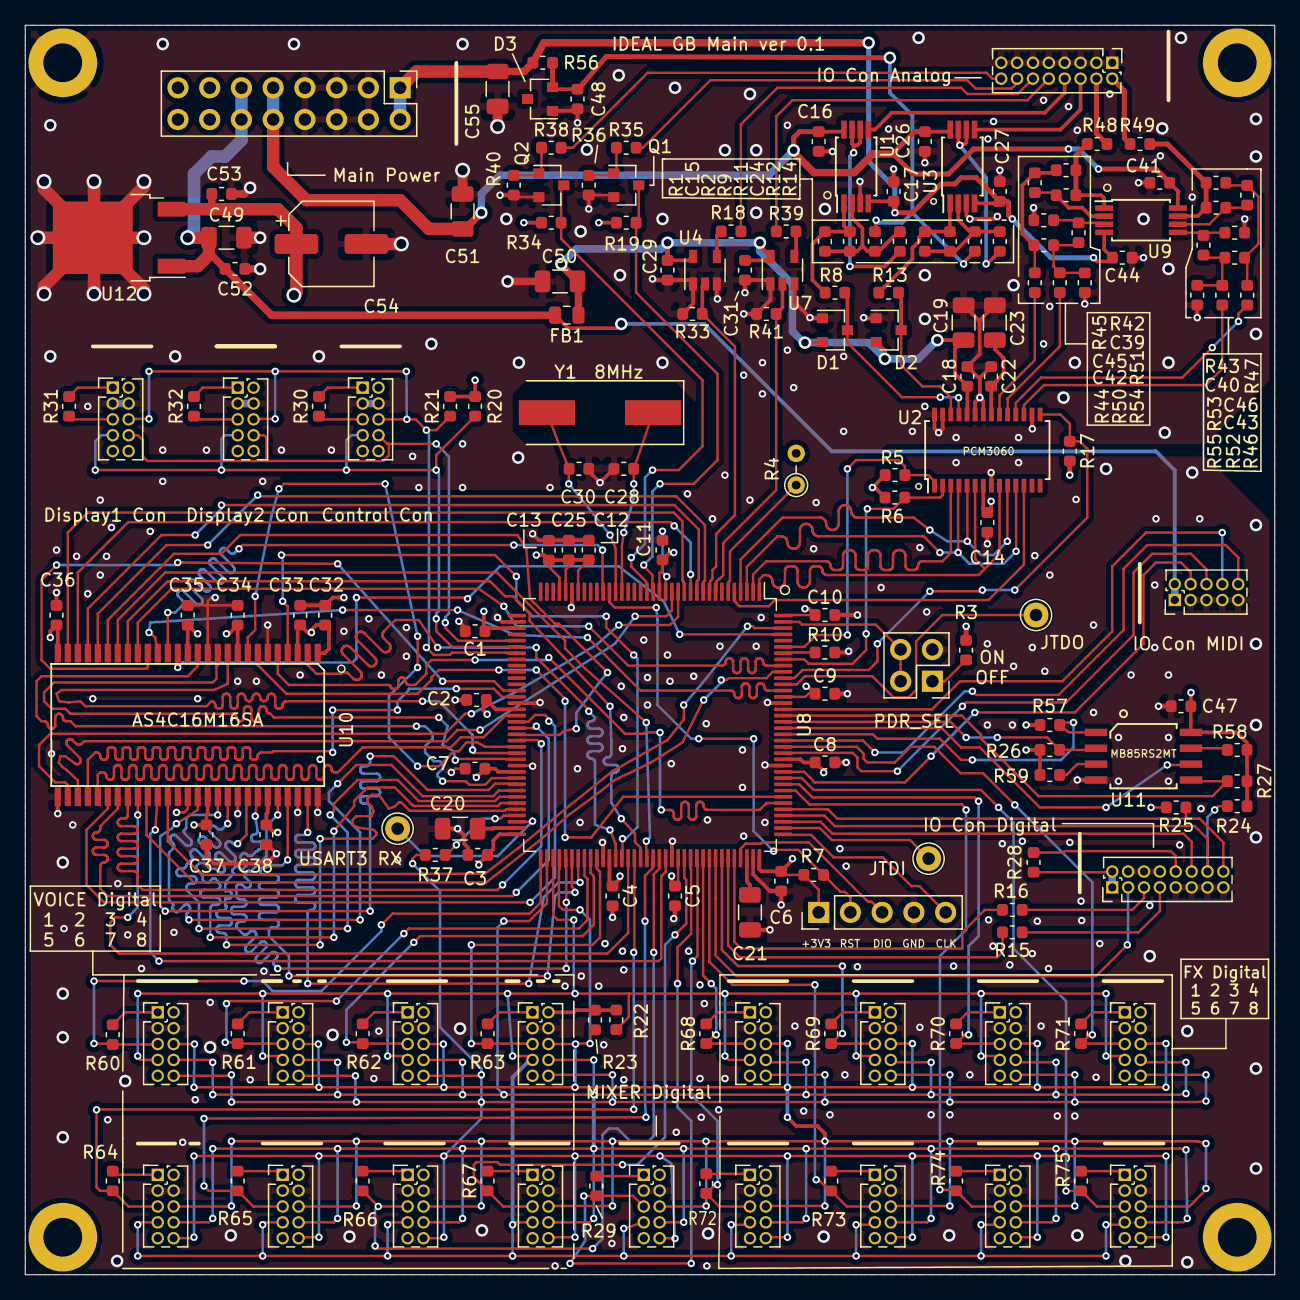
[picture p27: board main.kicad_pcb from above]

Board: 4 copper layers, 100.0 x 100.0 mm, 176 parts (0 on the bottom side), 154 nets.

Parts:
C1, C2, C3, C4, C5, C6, C7, C8, C9, C10, C11, C12, C13, C14, C16, C17, C18, C22, C25, C26, C27, C29, C31, C32, C33, C34, C35, C36, C37, C38, C41, C44, C47, C48, C52, C53: 100n; C_0603_1608Metric
C15, C24, C28, C30: 18p; C_0603_1608Metric
C19, C23: 10u; C_1206_3216Metric
C20, C21: 2.2u; C_1206_3216Metric
C39, C40, C45, C46: 470p; C_0603_1608Metric
C42, C43: 2.2n; C_0603_1608Metric
C49, C50, C51, C55: 22u; C_1206_3216Metric
C54: 100u; CP_Elec_6.3x5.3
D1, D2: BAT54S; SOT-23
D3: LM4040; SOT-23
FB1: Ferrite; R_0805_2012Metric
J1: IO_CON_ANALOG; PinHeader_2x08_P1.27mm_Vertical
J2: PDR_ON_SEL; PinHeader_2x02_P2.54mm_Vertical
J3: VOICE1_DIGITAL; PinHeader_2x05_P1.27mm_Vertical
J4: FX1_DIGITAL; PinHeader_2x05_P1.27mm_Vertical
J5: VOICE5_DIGITAL; PinHeader_2x05_P1.27mm_Vertical
J6: FX5_DIGITAL; PinHeader_2x05_P1.27mm_Vertical
J7: VOICE2_DIGITAL; PinHeader_2x05_P1.27mm_Vertical
J8: FX2_DIGITAL; PinHeader_2x05_P1.27mm_Vertical
J9: VOICE6_DIGITAL; PinHeader_2x05_P1.27mm_Vertical
J10: FX6_DIGITAL; PinHeader_2x05_P1.27mm_Vertical
J11: VOICE3_DIGITAL; PinHeader_2x05_P1.27mm_Vertical
J12: FX3_DIGITAL; PinHeader_2x05_P1.27mm_Vertical
J13: VOICE7_DIGITAL; PinHeader_2x05_P1.27mm_Vertical
J14: FX7_DIGITAL; PinHeader_2x05_P1.27mm_Vertical
J15: IO_CON_MIDI; PinHeader_2x05_P1.27mm_Vertical
J16: VOICE4_DIGITAL; PinHeader_2x05_P1.27mm_Vertical
J17: FX4_DIGITAL; PinHeader_2x05_P1.27mm_Vertical
J18: VOICE8_DIGITAL; PinHeader_2x05_P1.27mm_Vertical
J19: FX8_DIGITAL; PinHeader_2x05_P1.27mm_Vertical
J20: SWD_CON; PinHeader_1x05_P2.54mm_Vertical
J21: MIXER_DIGITAL; PinHeader_2x05_P1.27mm_Vertical
J22: DISPLAY1_DIGITAL; PinHeader_2x05_P1.27mm_Vertical
J23: IO_CON_DIGITAL; PinHeader_2x08_P1.27mm_Vertical
J24: POWER_CON; PinHeader_2x08_P2.54mm_Vertical
J25: CONTROL_DIGTAL; PinHeader_2x05_P1.27mm_Vertical
J26: DISPLAY2_DIGITAL; PinHeader_2x05_P1.27mm_Vertical
Q1, Q2: MMBT3904; SOT-23
R1, R11: 30k; R_0603_1608Metric
R2, R12: 120k; R_0603_1608Metric
R3, R5, R6, R7, R10, R17, R19, R20, R21, R22, R23, R24, R25, R26, R27, R28, R29, R30, R31, R32, R33, R34, R41, R57, R58, R59, R60, R61, R62, R63, R64, R65, R66, R67, R68, R69, R70, R71, R72, R73, R74, R75: 10k; R_0603_1608Metric
R4: 0; R_Axial_DIN0204_L3.6mm_D1.6mm_P2.54mm_Vertical
R8, R13, R48, R49: 470; R_0603_1608Metric
R9, R14: 200k; R_0603_1608Metric
R15, R16, R37: 10; R_0603_1608Metric
R18, R39, R45, R47, R51, R53: 1k; R_0603_1608Metric
R35, R36, R38, R40: 100k; R_0603_1608Metric
R42, R43, R54, R55: 12k; R_0603_1608Metric
R44, R46, R50, R52: 4.7k; R_0603_1608Metric
R56: 3.3k; R_0603_1608Metric
TP1: JTDI; Pin_D1.0mm_L10.0mm
TP2: JTDO; Pin_D1.0mm_L10.0mm
TP3: USART3_RX; Pin_D1.0mm_L10.0mm
U1, U3, U9: TL072; TSSOP-8_4.4x3mm_P0.65mm
U2: PCM3060; TSSOP-28_4.4x9.7mm_P0.65mm
U4, U7: 74AHCT1G125; SOT-23-5
U8: STM32F446ZETx; LQFP-144_20x20mm_P0.5mm
U10: AS4C16M16SA
U11: MB85RS2MT
U12: L7803; TO-252-2
Y1: 8MHz; Crystal_SMD_HC49-SD

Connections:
+3V3: C1.1, C2.1, C3.1, C4.1, C5.1, C6.1, C7.1, C8.1, C9.1, C10.1, C11.1, C12.1, C13.1, C14.1, C25.1, C32.1, C33.1, C34.1, C35.1, C36.1, C37.1, C38.1, C47.2, C53.1, C54.1, J3.1, J3.2, J4.1, J4.2, J5.1, J5.2, J6.1, J6.2, J7.1, J7.2, J8.1, J8.2, J9.1, J9.2, J10.1, J10.2, J11.1, J11.2, J12.1, J12.2, J13.1, J13.2, J14.1, J14.2, J16.1, J16.2, J17.1, J17.2, J18.1, J18.2, J19.1, J19.2, J20.1, J21.1, J21.2, J22.1, J22.2, J23.1, J23.2, J25.1, J25.2, J26.1, J26.2, R3.2, R4.2, R5.2, R6.2, R7.2, R17.2, R19.1, R20.2, R21.2, R22.2, R23.2, R24.2, R25.2, R26.2, R27.2, R28.2, R29.2, R30.2, R31.2, R32.2, R34.1, R57.2, R58.2, R59.2, R60.2, R61.2, R62.2, R63.2, R64.2, R65.2, R66.2, R67.2, R68.2, R69.2, R70.2, R71.2, R72.2, R73.2, R74.2, R75.2, U2.7, U8.17, U8.30, U8.32, U8.33, U8.39, U8.52, U8.62, U8.72, U8.84, U8.95, U8.108, U8.121, U8.131, U8.144, U10.1, U10.3, U10.9, U10.14, U10.27, U10.43, U10.49, U11.8, U12.3
+5V: C49.1, C52.1, FB1.2, J15.1, J15.2, J24.11, J24.12, U12.1
+5VA: C18.1, C19.1, C29.1, C31.1, C50.1, D1.2, D2.2, FB1.1, U2.24, U4.5, U7.5
+12V: C16.1, C26.1, C41.1, C51.1, J24.9, J24.10, U1.8, U3.8, U9.8
-12V: C17.2, C27.2, C44.2, C55.2, J24.1, J24.2, R56.2, U1.4, U3.4, U9.4
/FMC_A0: U8.10, U10.23
/FMC_A1: U8.11, U10.24
/FMC_A2: U8.12, U10.25
/FMC_A3: U8.13, U10.26
/FMC_A4: U8.14, U10.29
/FMC_A5: U8.15, U10.30
/FMC_A6: U8.50, U10.31
/FMC_A7: U8.53, U10.32
/FMC_A8: U8.54, U10.33
/FMC_A9: U8.55, U10.34
/FMC_A10: U8.56, U10.22
/FMC_A11: U8.57, U10.35
/FMC_A12: U8.87, U10.36
/FMC_BA0: U8.89, U10.20
/FMC_BA1: U8.90, U10.21
/FMC_D0: U8.85, U10.2
/FMC_D1: U8.86, U10.4
/FMC_D2: U8.114, U10.5
/FMC_D3: U8.115, U10.7
/FMC_D4: U8.58, U10.8
/FMC_D5: U8.59, U10.10
/FMC_D6: U8.60, U10.11
/FMC_D7: U8.63, U10.13
/FMC_D8: U8.64, U10.42
/FMC_D9: U8.65, U10.44
/FMC_D10: U8.66, U10.45
/FMC_D11: U8.67, U10.47
/FMC_D12: U8.68, U10.48
/FMC_D13: U8.77, U10.50
/FMC_D14: U8.78, U10.51
/FMC_D15: U8.79, U10.53
/FMC_NBL0: U8.141, U10.15
/FMC_NBL1: U8.142, U10.39
/FMC_SDCKE1: U8.135, U10.37
/FMC_SDCLK: U8.93, U10.38
/FMC_SDNCAS: U8.132, U10.17
/FMC_SDNE1: U8.136, U10.19
/FMC_SDNRAS: U8.49, U10.18
/FMC_SDNWE: U8.26, U10.16
/I2C_SCL: R5.1, U2.1, U8.139
/I2C_SDA: R6.1, U2.2, U8.137
/OTG_FS_DM: J23.7, R15.1
/OTG_FS_DP: J23.5, R16.1
/OTG_FS_VBUS: J23.3, U8.101
/SAI1_FS_A: U2.4, U2.11, U8.3
/SAI1_MCLK_A: U2.6, U2.9, U8.1
/SAI1_SCK_A: U2.5, U2.10, U8.4
/SAI1_SD_A: U2.12, U8.5
/SAI1_SD_B: U2.3, U8.2
/SPI1_MISO: J22.7, J25.7, J26.7, R20.1, U8.42
/SPI1_MOSI: J22.6, J25.6, J26.6, R21.1, U8.43
/SPI1_SCK: J22.8, J25.8, J26.8, U8.41
/SPI2_MISO: J3.7, J4.7, J5.7, J6.7, J7.7, J8.7, J9.7, J10.7, J11.7, J12.7, J13.7, J14.7, J16.7, J17.7, J18.7, J19.7, J21.7, R22.1, U8.75
/SPI2_MOSI: J3.6, J4.6, J5.6, J6.6, J7.6, J8.6, J9.6, J10.6, J11.6, J12.6, J13.6, J14.6, J16.6, J17.6, J18.6, J19.6, J21.6, R23.1, U8.76
/SPI2_SCK: J3.8, J4.8, J5.8, J6.8, J7.8, J8.8, J9.8, J10.8, J11.8, J12.8, J13.8, J14.8, J16.8, J17.8, J18.8, J19.8, J21.8, U8.74
/SPI3_MISO: J23.14, R24.1, U8.112
/SPI3_MOSI: J23.16, R25.1, U8.113
/SPI3_SCK: J23.12, U8.111
/SPI4_MISO: R26.1, U8.127, U11.2
/SPI4_MOSI: R27.1, U8.128, U11.5
/SPI4_SCK: U8.126, U11.6
/SWCLK: J20.5, U8.109
/SWDIO: J20.3, U8.105
/USART2_RX: J15.6, U8.122
/USART2_TX: J15.4, U8.119
/USART3_TX: J3.10, J4.10, J5.10, J6.10, J7.10, J8.10, J9.10, J10.10, J11.10, J12.10, J13.10, J14.10, J16.10, J17.10, J18.10, J19.10, J21.10, R37.1
/USART6_RX: J15.10, U8.124
/USART6_TX: J15.8, U8.129
/~CONTROL_SPI_CS: J25.5, R30.1
/~DAC_RESET: R17.1, U2.15, U8.134
/~DISPLAY1_SPI_CS: J22.5, R31.1
/~DISPLAY2_SPI_CS: J26.5, R32.1
/~FRAM_SPI_CS: R57.1, U8.125, U11.1
/~FX1_SPI_CS: J4.5, R68.1, U8.99
/~FX2_SPI_CS: J8.5, R69.1, U8.102
/~FX3_SPI_CS: J12.5, R70.1, U8.117
/~FX4_SPI_CS: J17.5, R71.1, U8.123
/~FX5_SPI_CS: J6.5, R72.1, U8.98
/~FX6_SPI_CS: J10.5, R73.1, U8.100
/~FX7_SPI_CS: J14.5, R74.1, U8.116
/~FX8_SPI_CS: J19.5, R75.1, U8.118
/~MIXER_SPI_CS: J21.5, R29.1, U8.97
/~RESET: J20.2, R7.1, U8.25
/~SD_SPI_CS: J23.10, R28.1
/~VOICE1_SPI_CS: J3.5, R60.1, U8.73
/~VOICE2_SPI_CS: J7.5, R61.1, U8.80
/~VOICE3_SPI_CS: J11.5, R62.1, U8.81
/~VOICE4_SPI_CS: J16.5, R63.1, U8.82
/~VOICE5_SPI_CS: J5.5, R64.1, U8.88
/~VOICE6_SPI_CS: J9.5, R65.1, U8.91
/~VOICE7_SPI_CS: J13.5, R66.1, U8.92
/~VOICE8_SPI_CS: J18.5, R67.1, U8.96
CV1_IN: J1.8, U1.5
CV1_OUT: J1.4, R48.2
CV2_IN: J1.6, U3.5
CV2_OUT: J1.2, R49.2
DAC_IN_L: D1.3, R8.1, U2.25
DAC_IN_R: D2.3, R13.1, U2.26
DAC_VOUTL+: R44.1, U2.20
DAC_VOUTL-: R50.1, U2.19
DAC_VOUTR+: R46.1, U2.18
DAC_VOUTR-: R52.1, U2.17
GATE1_IN: J1.16, R38.2
GATE1_IN_BUF_OUT: Q2.3, R34.2, U8.19
GATE1_OUT: J1.12, R18.1
GATE1_OUT_BUF_IN: R33.1, U4.2, U8.9
GATE2_IN: J1.14, R35.2
GATE2_IN_BUF_OUT: Q1.3, R19.2, U8.18
GATE2_OUT: J1.10, R39.1
GATE2_OUT_BUF_IN: R41.1, U7.2, U8.8
GND: C1.2, C2.2, C3.2, C4.2, C5.2, C6.2, C7.2, C8.2, C9.2, C10.2, C11.2, C12.2, C13.2, C14.2, C16.2, C17.1, C18.2, C19.2, C20.2, C21.2, C22.1, C23.1, C25.2, C26.2, C27.1, C28.2, C29.2, C30.2, C31.2, C32.2, C33.2, C34.2, C35.2, C36.2, C37.2, C38.2, C41.2, C44.1, C45.1, C46.1, C47.1, C48.2, C49.2, C50.2, C51.2, C52.2, C53.2, C54.2, C55.1, D1.1, D2.1, D3.1, J1.1, J1.3, J1.5, J1.7, J1.9, J1.11, J1.13, J1.15, J2.3, J3.3, J3.4, J4.3, J4.4, J5.3, J5.4, J6.3, J6.4, J7.3, J7.4, J8.3, J8.4, J9.3, J9.4, J10.3, J10.4, J11.3, J11.4, J12.3, J12.4, J13.3, J13.4, J14.3, J14.4, J15.3, J15.5, J15.7, J15.9, J16.3, J16.4, J17.3, J17.4, J18.3, J18.4, J19.3, J19.4, J20.4, J21.3, J21.4, J22.3, J22.4, J23.4, J23.6, J23.8, J23.9, J23.11, J23.13, J23.15, J24.3, J24.4, J24.5, J24.6, J24.7, J24.8, J25.3, J25.4, J26.3, J26.4, Q1.2, Q2.2, R10.2, R33.2, R36.2, R40.2, R41.2, R54.1, R55.1, U1.3, U2.8, U2.16, U2.22, U2.23, U2.27, U2.28, U3.3, U4.1, U4.3, U7.1, U7.3, U8.16, U8.31, U8.38, U8.51, U8.61, U8.83, U8.94, U8.107, U8.120, U8.130, U10.6, U10.12, U10.28, U10.41, U10.46, U10.52, U10.54, U11.4, U12.2
unnamed: C15.1, R1.2, R2.1, R9.1, U1.2
unnamed: C15.2, R1.1, R8.2, U1.1
unnamed: C20.1, U8.71
unnamed: C21.1, U8.106
unnamed: C22.2, C23.2, U2.21
unnamed: C24.1, R11.2, R12.1, R14.1, U3.2
unnamed: C24.2, R11.1, R13.2, U3.1
unnamed: C28.1, U8.23, Y1.1
unnamed: C30.1, U8.24, Y1.2
unnamed: C39.1, R45.2, U9.2
unnamed: C39.2, R42.2, R48.1, U9.1
unnamed: C40.1, R47.2, U9.6
unnamed: C40.2, R43.2, R49.1, U9.7
unnamed: C42.1, R42.1, R44.2, R45.1
unnamed: C42.2, R50.2, R51.1, R54.2
unnamed: C43.1, R43.1, R46.2, R47.1
unnamed: C43.2, R52.2, R53.1, R55.2
unnamed: C45.2, R51.2, U9.3
unnamed: C46.2, R53.2, U9.5
unnamed: J2.1, R3.1
unnamed: J2.2, J2.4, U8.143
unnamed: Q1.1, R35.1, R36.1
unnamed: Q2.1, R38.1, R40.1
unnamed: R4.1, U8.6
unnamed: R9.2, U1.6, U1.7
unnamed: R10.1, U8.138
unnamed: R14.2, U3.6, U3.7
unnamed: R15.2, U8.103
unnamed: R16.2, U8.104
unnamed: R18.2, U4.4
unnamed: R37.2, U8.69
unnamed: R39.2, U7.4
unnamed: R58.1, U11.7
unnamed: R59.1, U11.3
unnamed: TP1.1, U8.110
unnamed: TP2.1, U8.133
unnamed: TP3.1, U8.70
VREF_-10V: C48.1, D3.2, R2.2, R12.2, R56.1

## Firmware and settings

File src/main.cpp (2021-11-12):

/***********************************************************************************
 ***********************************************************************************
                                  Includes
 ***********************************************************************************
 **********************************************************************************/

#include <Arduino.h>
#include <stdlib.h>
#include <stepper.h>
#include <FS.h>
#include <WiFi.h>
#include <ESPAsync_WiFiManager.h>
#include <AsyncTCP.h>
#include <ESPAsyncWebServer.h>
#include <SPIFFS.h>
#include <DHT.h>
#include <U8g2lib.h>
#include <string.h>
#include <WiFiUdp.h>
#include <NTPClient.h>
#include <esp_now.h>

/***********************************************************************************
 ***********************************************************************************
                                  Define Pins
 ***********************************************************************************
 **********************************************************************************/
//#define LED_BUILTIN 2 // Pin D2 mapped to pin GPIO2/ADC12 of ESP32, control on-board LED

#define PIN_D0 0 // Pin D0 mapped to pin GPIO0/BOOT/ADC11/TOUCH1 of ESP32
#define PIN_D1 1 // Pin D1 mapped to pin GPIO1/TX0 of ESP32
#define PIN_D2 2 // Pin D2 mapped to pin GPIO2/ADC12/TOUCH2 of ESP32
#define PIN_D3 3 // Pin D3 mapped to pin GPIO3/RX0 of ESP32
#define PIN_D4 4 // Pin D4 mapped to pin GPIO4/ADC10/TOUCH0 of ESP32
#define PIN_D5 5 // Pin D5 mapped to pin GPIO5/SPISS/VSPI_SS of ESP32
#define PIN_D6 6 // Pin D6 mapped to pin GPIO6/FLASH_SCK of ESP32
#define PIN_D7 7 // Pin D7 mapped to pin GPIO7/FLASH_D0 of ESP32
#define PIN_D8 8 // Pin D8 mapped to pin GPIO8/FLASH_D1 of ESP32
#define PIN_D9 9 // Pin D9 mapped to pin GPIO9/FLASH_D2 of ESP32

#define PIN_D10 10 // Pin D10 mapped to pin GPIO10/FLASH_D3 of ESP32
#define PIN_D11 11 // Pin D11 mapped to pin GPIO11/FLASH_CMD of ESP32
#define PIN_D12 12 // Pin D12 mapped to pin GPIO12/HSPI_MISO/ADC15/TOUCH5/TDI of ESP32
#define PIN_D13 13 // Pin D13 mapped to pin GPIO13/HSPI_MOSI/ADC14/TOUCH4/TCK of ESP32
#define PIN_D14 14 // Pin D14 mapped to pin GPIO14/HSPI_SCK/ADC16/TOUCH6/TMS of ESP32
#define PIN_D15 15 // Pin D15 mapped to pin GPIO15/HSPI_SS/ADC13/TOUCH3/TDO of ESP32
#define PIN_D16 16 // Pin D16 mapped to pin GPIO16/TX2 of ESP32
#define PIN_D17 17 // Pin D17 mapped to pin GPIO17/RX2 of ESP32
#define PIN_D18 18 // Pin D18 mapped to pin GPIO18/VSPI_SCK of ESP32
#define PIN_D19 19 // Pin D19 mapped to pin GPIO19/VSPI_MISO of ESP32

#define PIN_D21 21 // Pin D21 mapped to pin GPIO21/SDA of ESP32
#define PIN_D22 22 // Pin D22 mapped to pin GPIO22/SCL of ESP32
#define PIN_D23 23 // Pin D23 mapped to pin GPIO23/VSPI_MOSI of ESP32
#define PIN_D24 24 // Pin D24 mapped to pin GPIO24 of ESP32
#define PIN_D25 25 // Pin D25 mapped to pin GPIO25/ADC18/DAC1 of ESP32
#define PIN_D26 26 // Pin D26 mapped to pin GPIO26/ADC19/DAC2 of ESP32
#define PIN_D27 27 // Pin D27 mapped to pin GPIO27/ADC17/TOUCH7 of ESP32

#define PIN_D32 32 // Pin D32 mapped to pin GPIO32/ADC4/TOUCH9 of ESP32
#define PIN_D33 33 // Pin D33 mapped to pin GPIO33/ADC5/TOUCH8 of ESP32
#define PIN_D34 34 // Pin D34 mapped to pin GPIO34/ADC6 of ESP32

// Only GPIO pin < 34 can be used as output. Pins >= 34 can be only inputs
// See .../cores/esp32/esp32-hal-gpio.h/c
//#define digitalPinIsValid(pin)          ((pin) < 40 && esp32_gpioMux[(pin)].reg)
//#define digitalPinCanOutput(pin)        ((pin) < 34 && esp32_gpioMux[(pin)].reg)
//#define digitalPinToRtcPin(pin)         (((pin) < 40)?esp32_gpioMux[(pin)].rtc:-1)
//#define digitalPinToAnalogChannel(pin)  (((pin) < 40)?esp32_gpioMux[(pin)].adc:-1)
//#define digitalPinToTouchChannel(pin)   (((pin) < 40)?esp32_gpioMux[(pin)].touch:-1)
//#define digitalPinToDacChannel(pin)     (((pin) == 25)?0:((pin) == 26)?1:-1)

#define PIN_D35 35 // Pin D35 mapped to pin GPIO35/ADC7 of ESP32
#define PIN_D36 36 // Pin D36 mapped to pin GPIO36/ADC0/SVP of ESP32
#define PIN_D39 39 // Pin D39 mapped to pin GPIO39/ADC3/SVN of ESP32

#define PIN_RX0 3 // Pin RX0 mapped to pin GPIO3/RX0 of ESP32
#define PIN_TX0 1 // Pin TX0 mapped to pin GPIO1/TX0 of ESP32

#define PIN_SCL 22 // Pin SCL mapped to pin GPIO22/SCL of ESP32
#define PIN_SDA 21 // Pin SDA mapped to pin GPIO21/SDA of ESP32

/***********************************************************************************
 ***********************************************************************************
                                      WiFi Setup
 ***********************************************************************************
 **********************************************************************************/
AsyncWebServer webServer(80);
DNSServer dnsServer;

/***********************************************************************************
 ***********************************************************************************
                                      NTP Setup
 ***********************************************************************************
 **********************************************************************************/
WiFiUDP ntpUDP;
NTPClient timeClient(ntpUDP);

String formattedDate;
String dayStamp;
String timeStamp;

/***********************************************************************************
 ***********************************************************************************
                                      OLED Setup
 ***********************************************************************************
 **********************************************************************************/
#ifdef U8X8_HAVE_HW_SPI
#include <SPI.h>
#endif
#ifdef U8X8_HAVE_HW_I2C
#include <Wire.h>
#endif

U8G2_SSD1306_128X32_UNIVISION_F_SW_I2C u8g2(U8G2_R0, /* clock=*/PIN_SCL, /* data=*/PIN_SDA, /* reset=*/U8X8_PIN_NONE);

/***********************************************************************************
 ***********************************************************************************
                                  Button Setup
 ***********************************************************************************
 **********************************************************************************/
#define BUTTON_A PIN_D26
#define BUTTON_B PIN_D25
#define BUTTON_C PIN_D33
#define BUTTON_D PIN_D32

/***********************************************************************************
 ***********************************************************************************
                                  Webserver setup
 ***********************************************************************************
 **********************************************************************************/
bool ledState = 0;
AsyncWebServer server(80);
AsyncWebSocket ws("/ws");
String message = "";
// Variables to save values from HTML form
String direction = "STOP";
String steps;
String timeOn;

bool newRequest = false;

// Initialize SPIFFS (SPIFFS is the file system the ESP32 uses)
void initSPIFFS()
{
  if (!SPIFFS.begin(true))
  {
    Serial.println("An error has occurred while mounting SPIFFS");
  }
  else
  {
    Serial.println("SPIFFS mounted successfully");
  }
}

void notifyClients(String state)
{
  ws.textAll(state);
}

void handleWebSocketMessage(void *arg, uint8_t *data, size_t len)
{
  AwsFrameInfo *info = (AwsFrameInfo *)arg;

  if (info->final && info->index == 0 && info->len == len && info->opcode == WS_TEXT)
  {
    data[len] = 0;
    // message is the data sent to the ESP when the 'submit' button is pressed
    message = (char *)data;
    // right now we have three variables we recieve in the message string
    // they are seperated by an "&"
    // indexOfFirst is the position of the first "&"
    // indexOfSec is the positon of the second "&"
    int indexOfFirst = message.indexOf("&");
    int indexOfSec = message.indexOf("&", indexOfFirst + 1);
    // steps is the value between the beginning of the string and "&"
    steps = message.substring(0, message.indexOf("&"));
    // direction is the value between the first "&" and second
    direction = message.substring(indexOfFirst + 1, indexOfSec);
    // timeOn is the value between the second "&" and the end of the string
    timeOn = message.substring(indexOfSec + 1, message.length());
    // printout information recived from website
    Serial.print("steps");
    Serial.println(steps);
    Serial.print("direction");
    Serial.println(direction);
    Serial.print("timeOn");
    Serial.println(timeOn);
    // tell the server that the motor is spinning to animate the gear icon
    notifyClients(direction);
    newRequest = true;
  }
}

void onEvent(AsyncWebSocket *server, AsyncWebSocketClient *client, AwsEventType type, void *arg, uint8_t *data, size_t len)
{
  switch (type)
  {
  case WS_EVT_CONNECT:
    Serial.printf("WebSocket client #%u connected from %s\n", client->id(), client->remoteIP().toString().c_str());
    // Notify client of motor current state when it first connects
    notifyClients(direction);
    break;
  case WS_EVT_DISCONNECT:
    Serial.printf("WebSocket client #%u disconnected\n", client->id());
    break;
  case WS_EVT_DATA:
    handleWebSocketMessage(arg, data, len);
    break;
  case WS_EVT_PONG:
  case WS_EVT_ERROR:
    break;
  }
}

void initWebSocket()
{
  ws.onEvent(onEvent);
  server.addHandler(&ws);
}

/***********************************************************************************
 ***********************************************************************************
                                  Stepper Motor initialize
 ***********************************************************************************
 **********************************************************************************/
// 28BYJ-48 uses 2048 setps per revolution
const int stepsPerRevolution = 2048;
#define IN1 PIN_D19
#define IN2 PIN_D18
#define IN3 PIN_D5
#define IN4 PIN_D17

// Set up stepper motor with correct wire configuration IN1, IN3, IN2, IN4
Stepper myStepper(stepsPerRevolution, IN1, IN3, IN2, IN4);
bool heatOn = false;

/***********************************************************************************
 ***********************************************************************************
                                  DHT11 Setup
 ***********************************************************************************
 **********************************************************************************/
#define DHTTYPE DHT11  // DHT 11
#define DHTPIN PIN_D27 // Pin 27

// setup the DHT sensor
DHT dht(DHTPIN, DHTTYPE);

// Define a time (in milliseconds) between sensor reads
#define DHT_UPDATE_DELAY 5000

float nowTemp = 0;
float highTemp = 80.00;
float lowTemp = 75.00;

/***********************************************************************************
 ***********************************************************************************
                                  millis() Setup
 ***********************************************************************************
 **********************************************************************************/
int currentMillis = 0;
int updateMillis = 0;

/***********************************************************************************
 ***********************************************************************************
                                  setup Function
 ***********************************************************************************
 **********************************************************************************/
void setup()
{
  // begin serial
  Serial.begin(115200);
  while (!Serial)
    ;
  // delay to make sure Serial is connected before next operation
  delay(200);

  // Setup Display
  u8g2.begin();

  // Setup Button

  pinMode(BUTTON_A, INPUT_PULLUP);
  pinMode(BUTTON_B, INPUT_PULLUP);
  pinMode(BUTTON_C, INPUT_PULLUP);
  pinMode(BUTTON_D, INPUT_PULLUP);

  Serial.print("\nStarting Async_AutoConnect_ESP32_minimal on " + String(ARDUINO_BOARD));
  Serial.println(ESP_ASYNC_WIFIMANAGER_VERSION);
  ESPAsync_WiFiManager ESPAsync_wifiManager(&webServer, &dnsServer, "Async_AutoConnect");
  // ESPAsync_wifiManager.resetSettings();   //reset saved settings
  ESPAsync_wifiManager.setAPStaticIPConfig(IPAddress(192, 168, 132, 1), IPAddress(192, 168, 132, 1), IPAddress(255, 255, 255, 0));
  ESPAsync_wifiManager.autoConnect("AutoConnectAP");
  u8g2.clearBuffer();                    // clear the internal memory
  u8g2.setFont(u8g2_font_ncenB08_tr);    // choose a suitable font
  u8g2.drawStr(0, 10, "Connect to AP!"); // write something to the internal memory
  u8g2.drawStr(0, 20, "192.168.132.1");
  u8g2.sendBuffer(); // transfer internal memory to the display
  Serial.print("\nConnect to the AutoConnectAP Access Point and point your browser to:192.168.132.1\n");
  delay(2000);
  if (WiFi.status() == WL_CONNECTED)
  {

    Serial.print(F("Connected. Local IP: "));
    Serial.println(WiFi.localIP());
    u8g2.clearBuffer();                        // clear the internal memory
    u8g2.setFont(u8g2_font_ncenB08_tr);        // choose a suitable font
    u8g2.drawStr(0, 10, "Connected to Wifi!"); // write something to the internal memory
    u8g2.drawStr(0, 20, WiFi.localIP().toString().c_str());
    u8g2.sendBuffer(); // transfer internal memory to the display
  }
  else
  {
    Serial.println(ESPAsync_wifiManager.getStatus(WiFi.status()));
  }

  // setup websocket
  initWebSocket();
  // setup SPIFFS
  initSPIFFS();
  // set the stepper speed
  myStepper.setSpeed(5);
  // Setup DHT
  dht.begin();
  // Web Server Root URL
  server.on("/", HTTP_GET, [](AsyncWebServerRequest *request)
            { request->send(SPIFFS, "/index.html", "text/html"); });

  server.serveStatic("/", SPIFFS, "/");
  // Starts the webserver on the ESP device
  server.begin();

  // Setup for time
  timeClient.begin();
  // Set offset time in seconds to adjust for your timezone, for example:
  // GMT +1 = 3600
  // GMT +8 = 28800
  // GMT -1 = -3600
  // GMT 0 = 0
  // PST is GMT -8
  //  3600*-8 = -28800
  timeClient.setTimeOffset(-28800);
}

/***********************************************************************************
 ***********************************************************************************
                                  loop Function
 ***********************************************************************************
 **********************************************************************************/
void loop()
{
  // int buttonStateA = 0;
  // int buttonStateB = 0;

  //  current time is the current time pulled from timeClient.getEpochTime();
  // int currentTime;

  // The updateTime is going to be the delay has expired.
  //  It is a static int set at zero because we want it to initally
  //  but we don't want it set at zero every time we enter the loop.
  //  It doesn't have to be zero, but it needs to be less than the
  //  current Epoch time because we want to trigger the read temp settings
  //  the first time.
  static int updateTime = 0;

  // Time client setup
  while (!timeClient.update())
  {
    timeClient.forceUpdate();
  }

  /*   // The formattedDate comes with the following format:
    // 2018-05-28T16:00:13Z
    // We need to extract date and time
    formattedDate = timeClient.getFormattedDate();
    Serial.println(formattedDate);

    // Extract date
    int splitT = formattedDate.indexOf("T");
    dayStamp = formattedDate.substring(0, splitT);
    Serial.print("DATE: ");
    Serial.println(dayStamp);
    // Extract time
    timeStamp = formattedDate.substring(splitT+1, formattedDate.length()-1);
    Serial.print("HOUR: ");
    Serial.println(timeStamp); */

  if (newRequest)
  {
    if (direction == "CW")
    {
      myStepper.step(steps.toInt());
      Serial.print("CW");
    }
    else
    {
      myStepper.step(-steps.toInt());
    }
    newRequest = false;
    notifyClients("stop");
  }
  ws.cleanupClients();
  // To prevent watchdog error, the program will make 100 steps each
  // cycle the program makes through loop().  When button is released,
  // the motor stops moving.
  if (digitalRead(BUTTON_A) == LOW)
    myStepper.step(100);
  if (digitalRead(BUTTON_B) == LOW)
    myStepper.step(-100);

  if (digitalRead(BUTTON_C) == LOW)
  {
    Serial.print("Button C pressed");
  }

  if (digitalRead(BUTTON_D) == LOW)
  {
    Serial.print("Button D pressed");
  }
  // Wait a few seconds between measurements.
  // Epoch time is the date in one long integer which makes it easy to compare time
  // between the last sample time and the current time
  if (millis() > updateMillis)
  {
    // Reading temperature or humidity takes about 250 milliseconds!
    // Sensor readings may also be up to 2 seconds 'old' (its a very slow sensor)
    float h = dht.readHumidity();
    // Read temperature as Celsius (the default)
    float t = dht.readTemperature();
    // Read temperature as Fahrenheit (isFahrenheit = true)
    float f = dht.readTemperature(true);
    nowTemp = f;
    // Check if any reads failed and exit early (to try again).
    if (isnan(h) || isnan(t) || isnan(f))
    {
      Serial.println(F("Failed to read from DHT sensor!"));
      return;
    }

    // Compute heat index in Fahrenheit (the default)
    float hif = dht.computeHeatIndex(f, h);
    // Compute heat index in Celsius (isFahreheit = false)
    float hic = dht.computeHeatIndex(t, h, false);
    char str[25];
    u8g2.clearBuffer();
    Serial.print(F("Humidity: "));
    u8g2.drawStr(0, 10, "Humidity: ");
    dtostrf(h, 3, 2, str);
    u8g2.drawStr(100, 10, str);
    Serial.print(h);
    Serial.print(F("%  Temperature: "));
    u8g2.drawStr(0, 20, "Temperature: ");
    dtostrf(f, 3, 2, str);
    u8g2.drawStr(100, 20, str);
    Serial.print(t);
    Serial.print(F("°C "));
    Serial.print(f);
    Serial.print(F("°F  Heat index: "));
    Serial.print(hic);
    Serial.print(F("°C "));
    Serial.print(hif);
    Serial.println(F("°F"));
    u8g2.sendBuffer();

    // Set current time to
    // currentTime = timeClient.getEpochTime();
    updateMillis = millis() + DHT_UPDATE_DELAY;

    if (nowTemp < lowTemp && !heatOn)
    {
      myStepper.step(-1000);
      heatOn = true;
    }
    if (nowTemp > highTemp && heatOn)
    {
      myStepper.step(1000);
      heatOn = false;
    }
  }
}

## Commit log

2021-10-20 added stepper motor datasheet and started on the schematic. Probably should move the schematic into its own folder.
    [CircuitBoard.kicad_pcb, CircuitBoard.sch]
2021-10-20 stepper driver board added
2021-10-20 added circuit board
    [CircuitBoard.sch]
2021-10-20 added kiCad esp32 model
2021-10-21 Added assignment3 documentation folder
    [CircuitBoard.sch]
2021-10-24 circuit board update
    [CircuitBoard.sch]
2021-10-24 Connects to internet. But webpage doesn't load up.
    [main.cpp]
2021-10-25 This mostly works. Stepper only spins clockwise though
2021-10-27 added DHT sensor library
2021-10-27 DHT11 works Added Fusion Schematic
    [CircuitBoard.kicad_pcb, CircuitBoard.sch, Schematic_v4.sch]
2021-10-28 Stepper moves cw and ccw now
2021-10-30 Added base LCD and Button stuff.
2021-11-03 Updated schematic
2021-11-04 added team3 to files
    [Team3_Schematic_v4.sch]
2021-11-08 added 2 buttons
2021-11-09 Added automatic stepper control based on temp
2021-11-09 Automatic stepper action based on temp
2021-11-09 Update README.md
    Added todo list and current functionality... made edit to formating
2021-11-09 All four buttons are now functional
2021-11-09 Updated Circuit Board
2021-11-10 Added Level0 and BOM
2021-11-10 Uses millis() instead of time to update sensor
2021-11-11 Updated Cad shcematic pdf
2021-11-16 circuitboard updates
2021-11-18 Added Assignments for week8
    [copper_bottom.GBL, copper_top.GTL, drill_1_16.XLN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]
2021-12-09 3D Print Prototypes
